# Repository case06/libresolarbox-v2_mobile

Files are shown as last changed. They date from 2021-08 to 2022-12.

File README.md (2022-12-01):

# libresolarbox-v2_mobile

[](
    https://opensourceecology.de)

LibreSolarBox V2 mobile powerbank

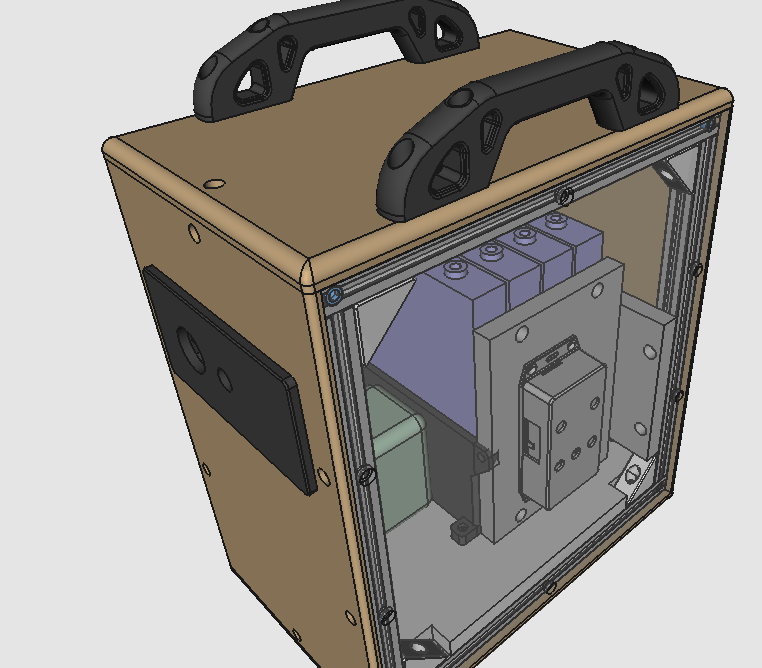
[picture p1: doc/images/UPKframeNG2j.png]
<p></p>

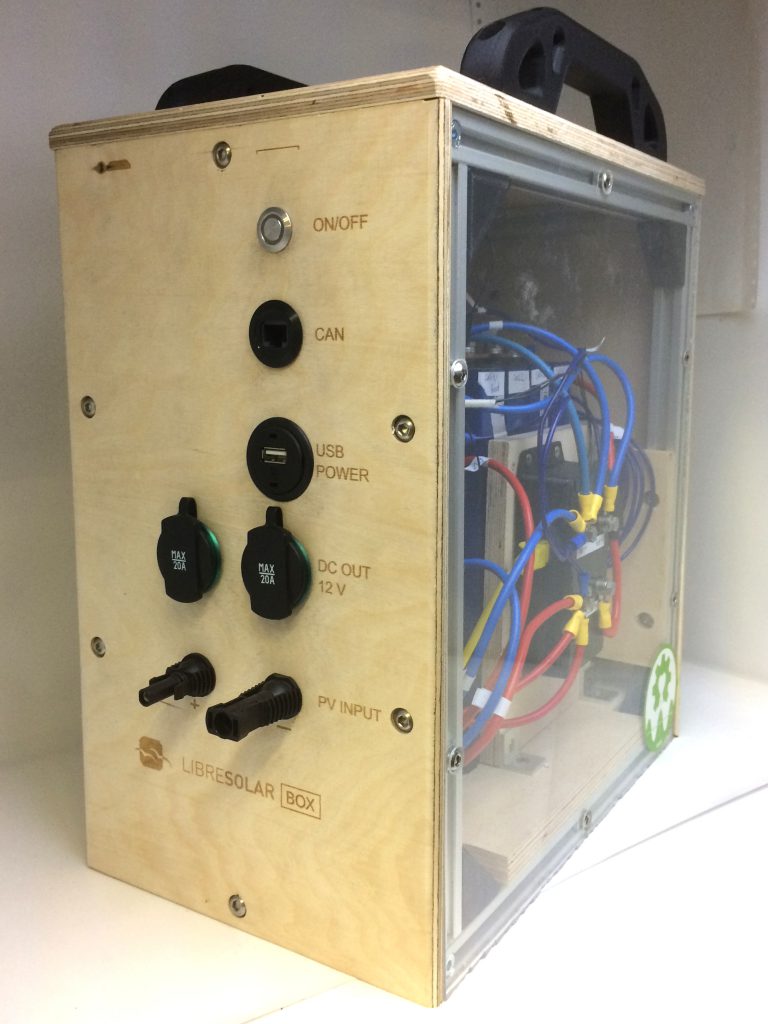
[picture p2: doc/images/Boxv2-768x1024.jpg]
<p></p>

Projektpage(s):

https://wiki.opensourceecology.de/SolarBox#Solarbox_Powerbank

https://github.com/CollectiveOpenSourceHardware/LibreSolarBox

Related projects:

https://libre.solar/

https://learn.libre.solar/

The projekt is based on the UniProKit 3D-part-library UPKlib V2.06, which is available at 

<a href="https://github.com/case06/upklib_v2"> https://github.com/case06/upklib_v2 </a>

The FreeCAD-sourcefiles of the current version can be viewed or modified with FreeCAD version 18 and 19

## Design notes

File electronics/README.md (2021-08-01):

# libresolarbox-v2_mobile electronics
Electronics for LibreSolarBox V2 mobile powerbank

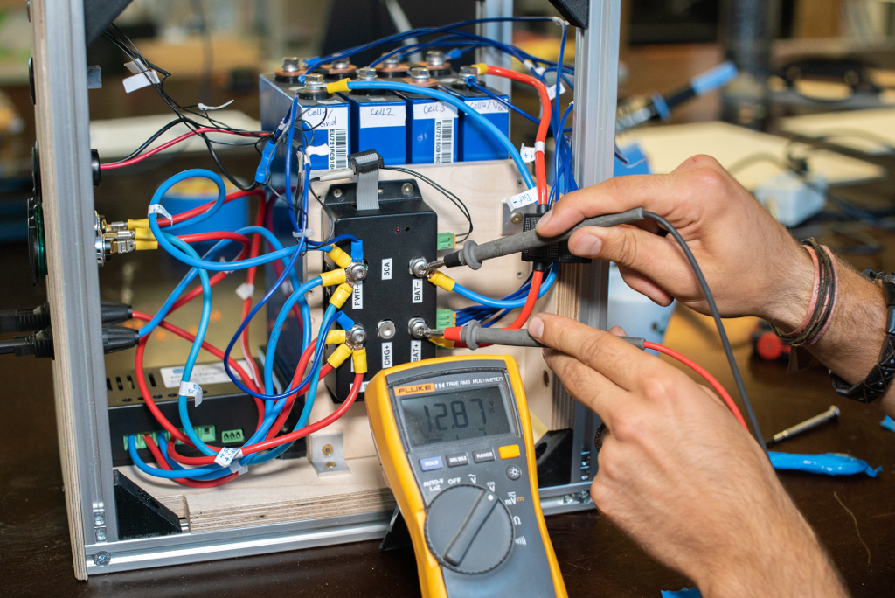
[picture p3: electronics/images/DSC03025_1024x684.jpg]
<p></p>

## Electronics Components:

### PCBs:

The electronic interieur of the Box can be filled with lots of different components from different sources but should in general cover the following basic functions:

- LiFePo4-Cells
- Battery-Managment-System (BMS)
- Solar-Charger
- Interfacing 
- communications gateway

As a reference we relay here to some OpenHardware pcb-versions which were developed by the LibreSolar-project:

#### Solarcharger: MPPT-2420 LC

https://github.com/LibreSolar/mppt-2420-lc

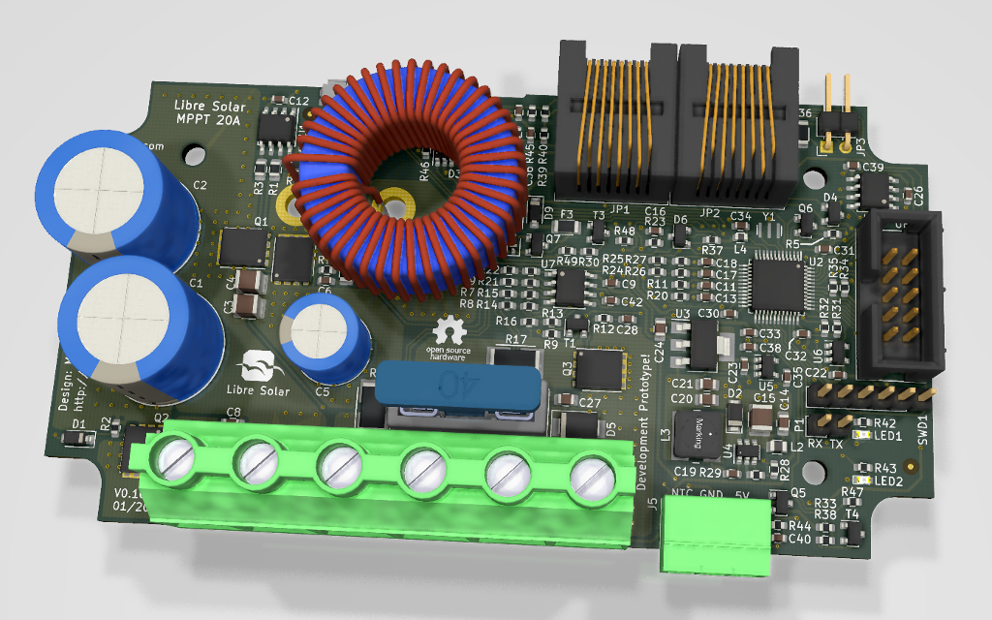
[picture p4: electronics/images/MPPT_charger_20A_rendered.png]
<p></p>
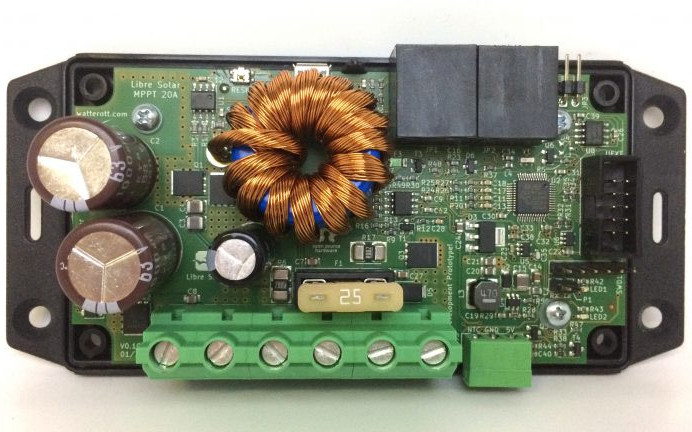
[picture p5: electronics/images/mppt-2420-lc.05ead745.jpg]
<p></p>

#### BatteryManagementSystem: BMS-8s50 IC

https://github.com/LibreSolar/bms-8s50-ic

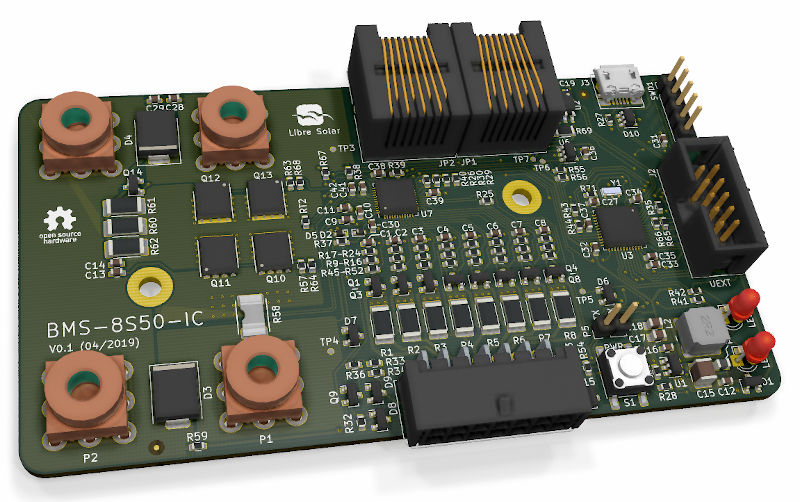
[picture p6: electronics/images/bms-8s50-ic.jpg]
<p></p>
<p></p>

#### Gateway: RPi-Can

https://github.com/LibreSolar/rpi-can

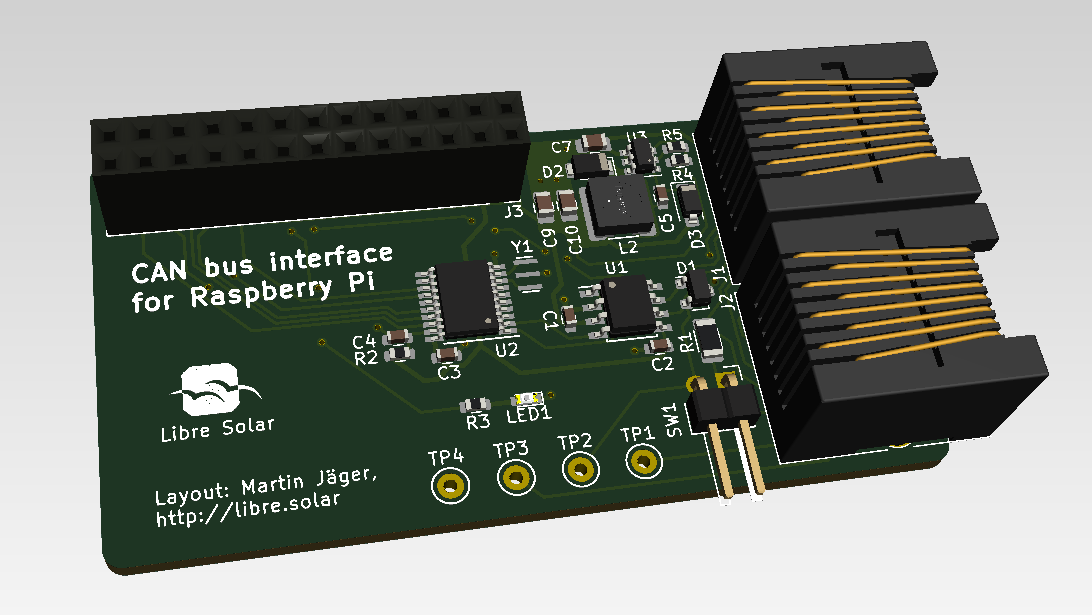
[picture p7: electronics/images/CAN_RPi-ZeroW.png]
<p></p>
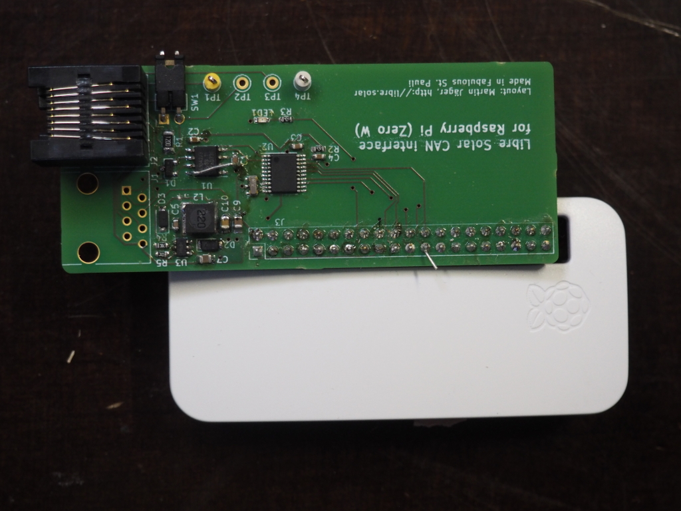
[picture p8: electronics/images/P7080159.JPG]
<p></p>

All other parts are standard-parts from regular sources.

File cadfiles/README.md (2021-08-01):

# libresolarbox_v2_mobile cadfiles
Cadfiles for LibreSolarBox V2 mobile powerbank

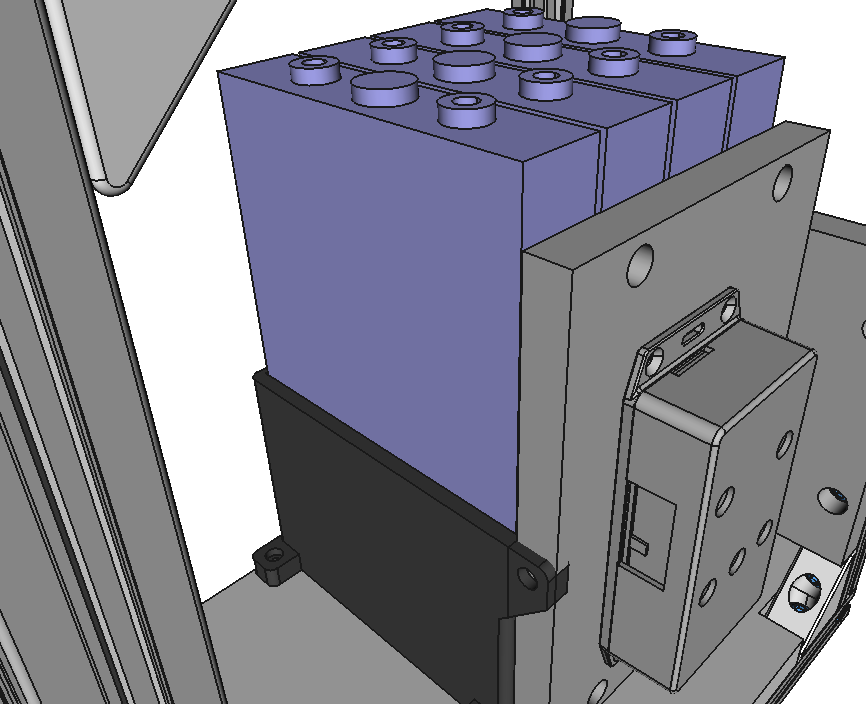
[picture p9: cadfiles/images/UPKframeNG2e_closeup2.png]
LibreSolarBox V2 mobile powerbank
<p></p>

All the parts of the boxframe are available also as singlepart-cadfile within the UPKlib V2 Boxset:

https://github.com/case06/upklib_v2/tree/master/boxset

Projektpage(s):

https://wiki.opensourceecology.de/Upklib#Set_Box

https://wiki.opensourceecology.de/Erg%C3%A4nzungs-Set_Boxset

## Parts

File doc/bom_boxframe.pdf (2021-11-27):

Sheet1

Page 1

BOM BoxSet V.2 mobile UniProKit UPKlib V2.06

Partname | UPK-PartNo. Quantity | Description | Supplier

Frame:
Tslot32 | 17092207 | 4 | Upright framepart | ML
Tslot32con | 17092218 | 4 | Side framepart | ML
Tslot16 | 17092205 | 4 | Cross-link framepart | ML
M6x25cyl | 17092307 | 8 | Screw f. TSlot direct-corner-connection DIN 7984 | SP, ML
M6x12 | 17092304 | 16 | Screw f. Right-Angle-Connector, ISO7380 | SP, ML
M6x16 | 17092305 | 12 | Screw f. connect Mountplates, ISO7380 | SP, ML
M6nutplate | 17092309 | 28 | Nutplate for Right-Angle-Connector | ML
RAconnector | 17092313 | 8 | Right-Angle-Connector, ABS black | 3DP, ML
Front_plate | 17092502 | 2 | Inner Front- and Mountplate | ML
Bottom_plate | 17092501 | 1 | Inner Bottom-Plate | ML
Angle4 | 17092224 | 2 | Connect Mountplates | ML
3.5x16 woodscrew | 18081701 | 16 | Screw f. connect Mountplates DIN 7997 | SP, ML
Handle | 17122301 | 2 | Handle, ABS black | 3DP, ML

Cover:
M6x8 | 17092303 | 24 | Screw f. CoverPlates ISO7380 | SP, ML
M6x25cyl | 17092307 | 8 | Screw f. Handles plus 12mm Plate DIN7984 | SP, ML
M6x12 | 17092304 | 8 | Screw f. TopBottom-Cover ISO7380 | SP, ML
M6nutplate | 17092309 | 40 | Nutplate for CoverPlates | ML
TopBottomNG2b | 18011601 | 2 | Top,Bottom Film Faced Phenolic Plywood 12mm | ML
FrontbackNG2b | 18011602 | 1 | Front Cover Film Faced Phenolic Plywood 6.5mm | ML
FrontbackNG2c_ifmount | 18011603 | 1 | Back Cover Film Faced Phenolic Plywood 6.5mm | ML
SideCoverNG2_transp | 18011604 | 1 | Side Cover Acryl-glas 6mm | ML
SideCoverNG2 | 18081702 | 1 | Side Cover Film Faced Phenolic Plywood 6.5mm | ML
IfmountNG1c | 18050303 | 1 | Interface mountplate, ABS black | 3DP, ML

Sheet1

Page 2

Std.-Part | SP Standard-Part, widely available from several sources
3d-Printable | 3DP 3d-printable part, see project sources

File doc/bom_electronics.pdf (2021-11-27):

Sheet1

Page 1

BOM Electronics LibreSolarBox V.2 mobile

Partname | UPK-PartNo. Quantity | Description | Supplier

housing

All UPKlib boxset parts | | External Project | EPS1
batterymount 1c | 1 | Holder for LiFePo4-cells | 3DP
bms-case1c | 1 | Housing for BMS pcb | 3DP
mppt-2420lc-housing | 1 | Hammond Mfg 1591XXCFL housing | SP

Solarcharger:

LibreSolar_MPPT-Charger_20A | 1 | EPS2

BMS:
LibreSolar_BMS-5s | 1 | EPS3

Gateway:
RPi-Can | 1 | External Project, optional | EPS4

Buck-Converter:

Buck-Converter-12-5 | 1 | Buck-Converter from 12V to 5V, optional | SP

Interface:

Display | 1 | | SP
DC_Out_Plug1 | 1 | DC output plugs (12V car plug, 2x) | SP
USB_adapter | 1 | USB 5V outlet plug w/ integr. 12V→5V stepdown | SP
PV_in_MC4 | 2 | SP

MPPT-2420 LC, External Project

BMS-8s50 IC, External Project

i2c character display or - e-paper display+cable, Optional

Pair of MC4 Solar input plugs, eg. Weidmüller PV Stick

Sheet1

Page 2

SW_Push_LED | 1 | ON/OFF switch, pushbutton, integrated LED | SP
CAN output plug | 2 | RJ45 jack, optional | SP

Internal Connections and Hardware:

Power wire | 2 | Power wire (6mm^2, red+blue, each 1m) | SP
Balancer cable | 1 | Balancing wire for Cells (2mm^2, 2m) | SP
Wire - thick - red & blue | 10 | | SP
Wire - thin - blue | 6 | | SP
Wire - very thin - black | 3 | | SP
Cat5 cable | 3 | | SP
F1 – Fuse | 1 | 20A | SP
wire connectors | 1 | | SP
Battery Cell | 4 | CALB 72 Ah CAM, LiFePo4 | SP
Battery Cell connector plates | 3 | for CAM72, copper | SP
Battery Cell connector screw | 8 | | SP
RasPi - CAN to wifi connection | 1 | | SP
Screw - MPPT/BMS connection | 10 | 5x2 | SP
Screw - MPPT/BMS installation | 8 | 4x2 | SP
Ferrules | 1 | Set with 6mm^2 and 2mm^2 | SP
Cable lugs | 1 | | SP

to all main connection from battery to MPPT & BMS 0.25m (5 Red color & 5 Blue colour)

to connect BMS to battery to check Battery status 0.4mx6 (blue colour)

to connect power button to MPPT,
0.25mx2, 0.4mx1

CAN communication wire (ethernet cable, 0,25m), Optional

M8x10, DIN 912

Set with flat- and ring-lugs of different hole-sizes (8, 6, 5mm)

Sheet1

Page 3

Supplier | Id | URL
Std.-Part | SP | Standard-Part, widely available from several sources
Makers-Lab | ML | http:makers-lab.de
3d-Printable | 3DP | 3d-printable part, see project sources
external project | EPS | Sources from an external project
external project | EPS1 | https://github.com/case06/upklib_v2/tree/master/boxset
external project | EPS2 | https://github.com/LibreSolar/mppt-2420-lc
external project | EPS3 | https://github.com/LibreSolar/bms-8s50-ic
external project | EPS4 | https://github.com/LibreSolar/rpi-can

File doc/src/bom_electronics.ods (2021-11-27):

BOM Electronics LibreSolarBox V.2 mobile
Partname |  | UPK-PartNo. | Quantity | Description | Supplier
housing
All UPKlib boxset parts |  |  |  | External Project | EPS1
batterymount 1c |  |  | 1 | Holder for LiFePo4-cells | 3DP
bms-case1c |  |  | 1 | Housing for BMS pcb | 3DP
mppt-2420lc-housing |  |  | 1 | Hammond Mfg 1591XXCFL housing | SP
Solarcharger:
LibreSolar_MPPT-Charger_20A |  |  | 1 | MPPT-2420 LC, External Project | EPS2
BMS:
LibreSolar_BMS-5s |  |  | 1 | BMS-8s50 IC, External Project | EPS3
Gateway:
RPi-Can |  |  | 1 | External Project, optional | EPS4
Buck-Converter:
Buck-Converter-12-5 |  |  | 1 | Buck-Converter from 12V to 5V, optional | SP
Interface:
Display |  |  | 1 | i2c character display or - e-paper display+cable, Optional | SP
DC_Out_Plug1 |  |  | 1 | DC output plugs (12V car plug, 2x) | SP
USB_adapter |  |  | 1 | USB 5V outlet plug w/ integr. 12V→5V stepdown | SP
PV_in_MC4 |  |  | 2 | Pair of MC4 Solar input plugs, eg. Weidmüller PV Stick | SP
SW_Push_LED |  |  | 1 | ON/OFF switch, pushbutton, integrated LED | SP
CAN output plug |  |  | 2 | RJ45 jack, optional | SP
Internal Connections and Hardware:
Power wire |  |  | 2 | Power wire (6mm^2, red+blue, each 1m) | SP
Balancer cable |  |  | 1 | Balancing wire for Cells (2mm^2, 2m) | SP
Wire - thick - red & blue |  |  | 10 | to all main connection from battery to MPPT & BMS 0.25m (5 Red color & 5 Blue colour) | SP
Wire - thin - blue |  |  | 6 | to connect BMS to battery to check Battery status 0.4mx6 (blue colour) | SP
Wire - very thin - black |  |  | 3 | to connect power button to MPPT, 0.25mx2, 0.4mx1 | SP
Cat5 cable |  |  | 3 | CAN communication wire (ethernet cable, 0,25m), Optional | SP
F1 – Fuse |  |  | 1 | 20A | SP
wire connectors |  |  | 1 |  | SP
Battery Cell |  |  | 4 | CALB 72 Ah CAM, LiFePo4 | SP
Battery Cell connector plates |  |  | 3 | for CAM72, copper | SP
Battery Cell connector screw |  |  | 8 | M8x10, DIN 912 | SP
RasPi - CAN to wifi connection |  |  | 1 |  | SP
Screw - MPPT/BMS connection |  |  | 10 | 5x2 | SP
Screw - MPPT/BMS installation |  |  | 8 | 4x2 | SP
Ferrules |  |  | 1 | Set with 6mm^2 and 2mm^2 | SP
Cable lugs |  |  | 1 | Set with flat- and ring-lugs of different hole-sizes (8, 6, 5mm) | SP
Supplier | Id | URL
Std.-Part | SP | Standard-Part, widely available from several sources
Makers-Lab | ML | http:makers-lab.de
3d-Printable | 3DP | 3d-printable part, see project sources
external project | EPS | Sources from an external project
external project | EPS1 | https://github.com/case06/upklib_v2/tree/master/boxset
external project | EPS2 | https://github.com/LibreSolar/mppt-2420-lc
external project | EPS3 | https://github.com/LibreSolar/bms-8s50-ic
external project | EPS4 | https://github.com/LibreSolar/rpi-can

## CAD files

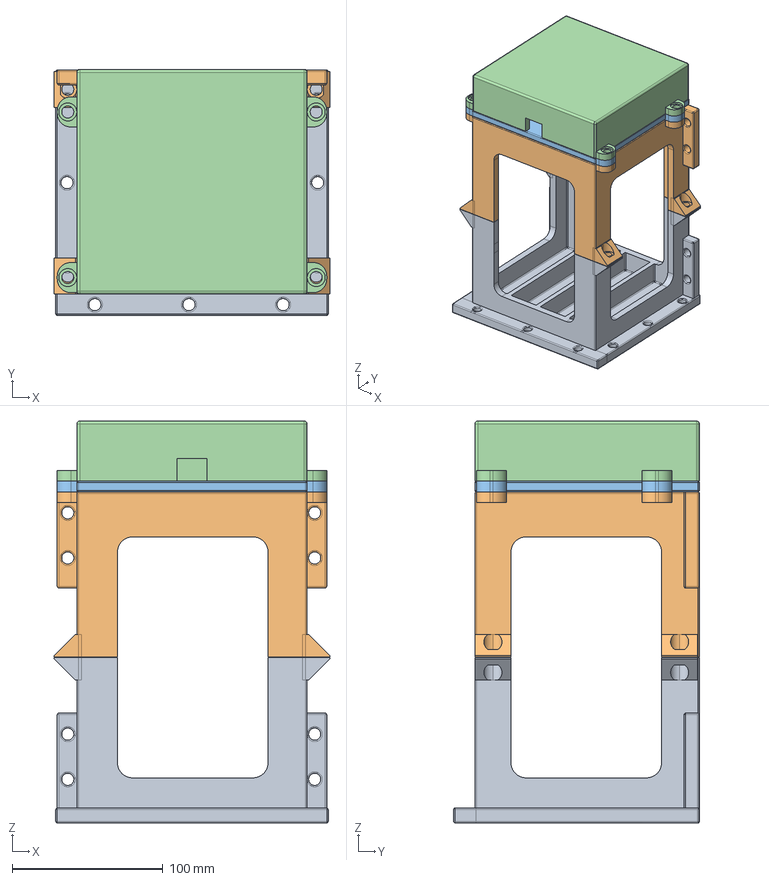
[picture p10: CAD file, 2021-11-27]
cadfiles/batterymount_full-closure.FCStd
183.0 x 163.2 x 267.0 mm
Lower_part_1
Upper_part_2
Top_sheet_3
Cover_part_4

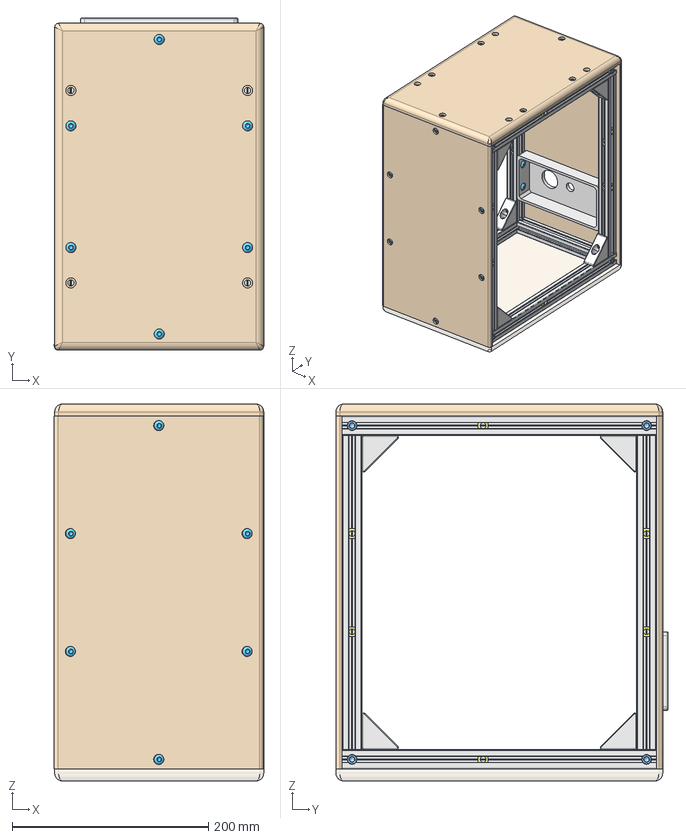
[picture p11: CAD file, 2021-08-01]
doc/src/src_boxassemblyguide1d/cover/cover8.fcstd
213.5 x 338.5 x 384.0 mm
tslot32con
tslot16
tslot16_001
tslot32con_001
M6x25-Screw
M6x25-Screw004
M6x25-Screw005
M6x25-Screw006
tslot32con001
tslot041
tslot16_002
tslot32con_002
M6x25-Screw012
M6x25-Screw015
M6x25-Screw017
M6x25-Screw016
m6nutplate020uf
m6nutplate021lf
m6nutplate022lf
m6nutplate023lf
m6nutplate024lf
m6nutplate025lf
m6nutplate026lf
m6nutplate027lf
m6nutplate028uf
m6nutplate029uf
m6nutplate030lf
m6nutplate031lf
m6nutplate032uf
m6nutplate033lf
upright4
m6nutplate025uf001
m6nutplate022uf001
m6nutplate031lf001
M6x12-Screw022
upright005
m6nutplate031lf002
M6x12-Screw025
upright006
m6nutplate031lf003
M6x12-Screw028
upright007
m6nutplate031lf004
M6x12-Screw031
m6nutplatesidecover
m6nutplatesidecover001
m6nutplatesidecover002
m6nutplatesidecover003
m6nutplatesidecover004
m6nutplatesidecover005
m6nutplatesidecover006
m6nutplatesidecover007
m6nutplatefrontcover
m6nutplatefrontcover001
m6nutplatefrontcover002
m6nutplatefrontcover003
m6nutplatefrontcover004
m6nutplatefrontcover005
m6nutplatefrontcover006
m6nutplatefrontcover007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

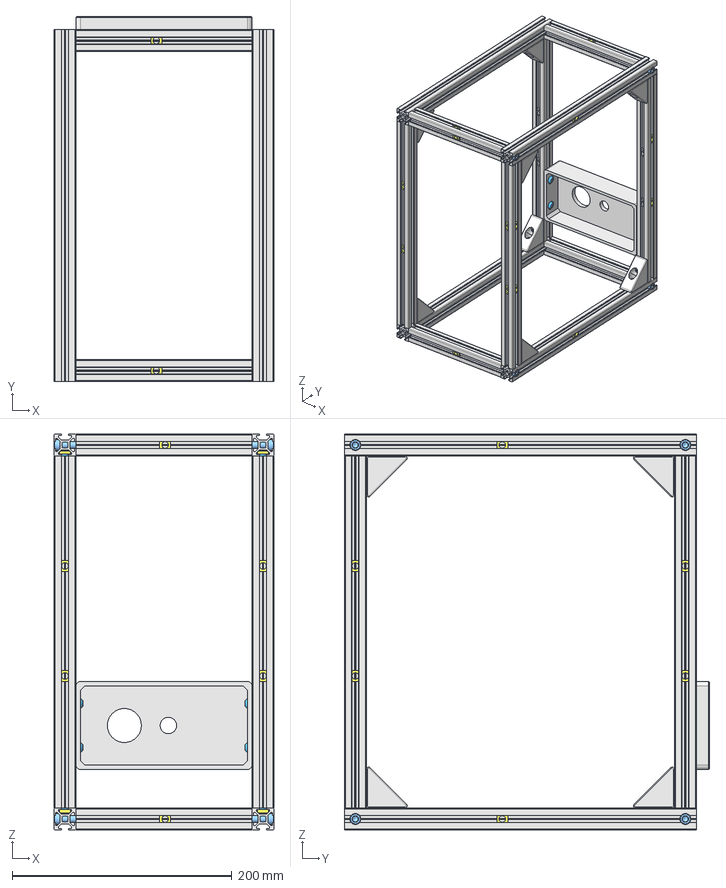
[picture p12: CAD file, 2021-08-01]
doc/src/src_boxassemblyguide1d/ifmountframe/ifmountframe1.fcstd
200.0 x 332.0 x 360.0 mm
tslot32con
tslot16
tslot16_001
tslot32con_001
M6x25-Screw
M6x25-Screw004
M6x25-Screw005
M6x25-Screw006
tslot32con001
tslot041
tslot16_002
tslot32con_002
M6x25-Screw012
M6x25-Screw015
M6x25-Screw017
M6x25-Screw016
m6nutplate020uf
m6nutplate021lf
m6nutplate022lf
m6nutplate023lf
m6nutplate024lf
m6nutplate025lf
m6nutplate026lf
m6nutplate027lf
m6nutplate028uf
m6nutplate029uf
m6nutplate030lf
m6nutplate031lf
m6nutplate032uf
m6nutplate033lf
upright4
m6nutplate025uf001
m6nutplate022uf001
m6nutplate031lf001
M6x12-Screw022
upright005
m6nutplate031lf002
M6x12-Screw025
upright006
m6nutplate031lf003
M6x12-Screw028
upright007
m6nutplate031lf004
M6x12-Screw031
m6nutplatesidecover
m6nutplatesidecover001
m6nutplatesidecover002
m6nutplatesidecover003
m6nutplatesidecover004
m6nutplatesidecover005
m6nutplatesidecover006
m6nutplatesidecover007
m6nutplatefrontcover
m6nutplatefrontcover001
m6nutplatefrontcover002
m6nutplatefrontcover003
m6nutplatefrontcover004
m6nutplatefrontcover005
m6nutplatefrontcover006
m6nutplatefrontcover007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

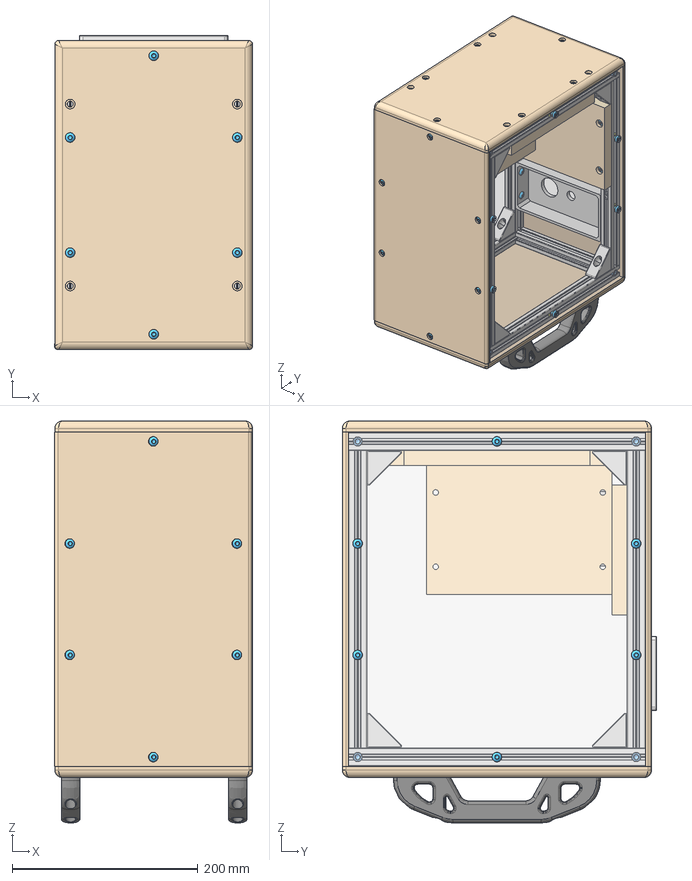
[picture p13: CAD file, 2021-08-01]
doc/src/src_boxassemblyguide1d/innerplates/innerplate6.fcstd
213.5 x 338.5 x 433.0 mm
tslot32con
tslot16
tslot16_001
tslot32con_001
M6x25-Screw
M6x25-Screw004
M6x25-Screw005
M6x25-Screw006
tslot32con001
tslot041
tslot16_002
tslot32con_002
M6x25-Screw012
M6x25-Screw015
M6x25-Screw017
M6x25-Screw016
m6nutplate020uf
m6nutplate021lf
m6nutplate022lf
m6nutplate023lf
m6nutplate024lf
m6nutplate025lf
m6nutplate026lf
m6nutplate027lf
m6nutplate028uf
m6nutplate029uf
m6nutplate030lf
m6nutplate031lf
m6nutplate032uf
m6nutplate033lf
m6nutplate023
upright4
m6nutplate025uf001
m6nutplate022uf001
m6nutplate031lf001
M6x12-Screw022
upright005
m6nutplate031lf002
M6x12-Screw025
upright006
m6nutplate031lf003
M6x12-Screw028
upright007
m6nutplate031lf004
M6x12-Screw031
m6nutplatesidecover
m6nutplatesidecover001
m6nutplatesidecover002
m6nutplatesidecover003
m6nutplatesidecover004
m6nutplatesidecover005
m6nutplatesidecover006
m6nutplatesidecover007
m6nutplatefrontcover
m6nutplatefrontcover001
m6nutplatefrontcover002
m6nutplatefrontcover003
m6nutplatefrontcover004
m6nutplatefrontcover005
m6nutplatefrontcover006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

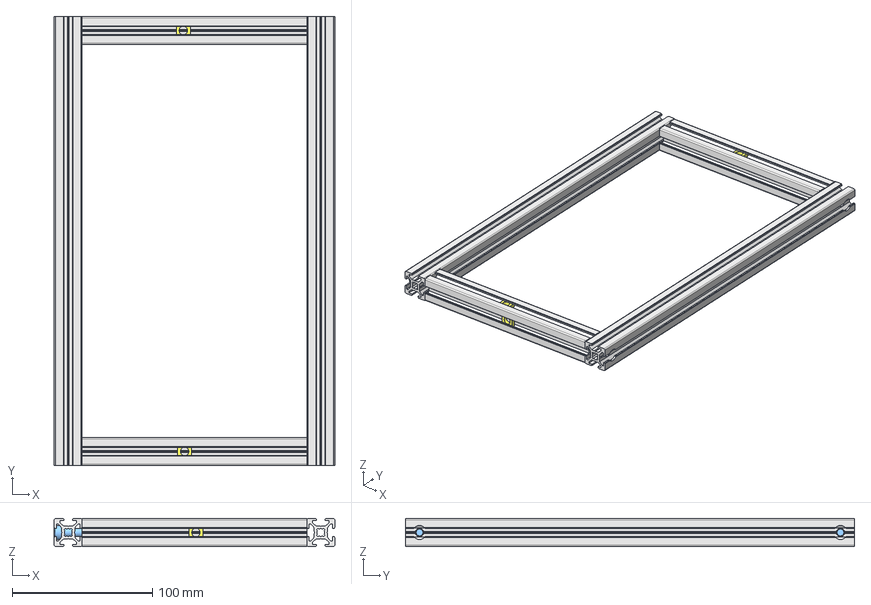
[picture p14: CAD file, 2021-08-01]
doc/src/src_boxassemblyguide1d/lower_frame/lowerframe1.fcstd
200.0 x 320.0 x 20.0 mm
tslot32con001
tslot041
tslot16_002
tslot32con_002
M6x25-Screw007
M6x25-Screw008
m6nutplate020
m6nutplate021
m6nutplate022
m6nutplate023
m6nutplate024
m6nutplate025
m6nutplate026
m6nutplate027

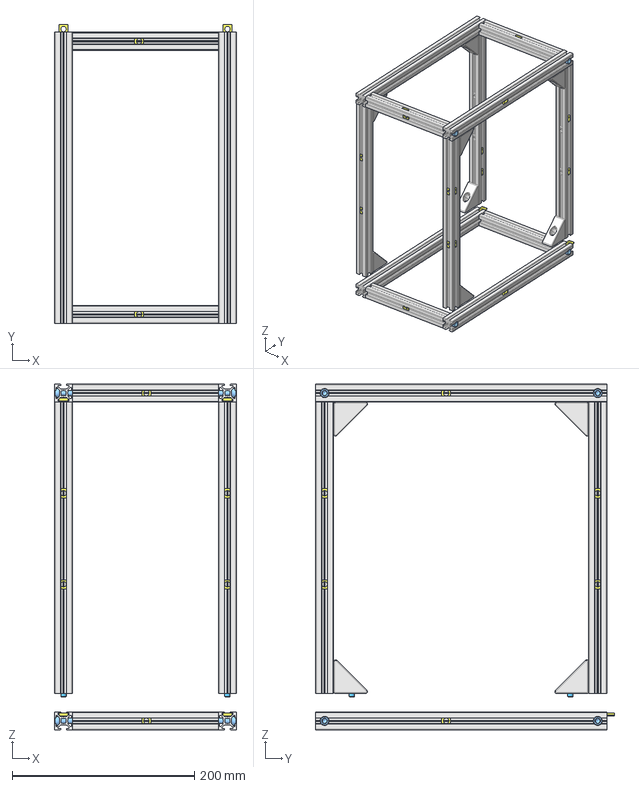
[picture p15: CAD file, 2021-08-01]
doc/src/src_boxassemblyguide1d/rawframe/rawframe8b.fcstd
200.0 x 328.4 x 380.0 mm
tslot32con
tslot16
tslot16_001
tslot32con_001
M6x25-Screw
M6x25-Screw004
M6x25-Screw005
M6x25-Screw006
tslot32con001
tslot041
tslot16_002
tslot32con_002
M6x25-Screw012
M6x25-Screw015
M6x25-Screw017
M6x25-Screw016
m6nutplate020uf
m6nutplate021lf
m6nutplate022lf
m6nutplate023lf
m6nutplate024lf
m6nutplate025lf
m6nutplate026lf
m6nutplate027lf
m6nutplate028uf
m6nutplate029uf
m6nutplate030lf
m6nutplate031lf
m6nutplate032uf
m6nutplate033lf
upright4
m6nutplate025uf001
m6nutplate022uf001
m6nutplate031lf001
M6x12-Screw022
upright005
m6nutplate031lf002
M6x12-Screw025
upright006
m6nutplate031lf003
M6x12-Screw028
upright007
m6nutplate031lf004
M6x12-Screw031
m6nutplatesidecover
m6nutplatesidecover001
m6nutplatesidecover002
m6nutplatesidecover003
m6nutplatesidecover004
m6nutplatesidecover005
m6nutplatesidecover006
m6nutplatesidecover007
m6nutplatefrontcover
m6nutplatefrontcover001
m6nutplatefrontcover002
m6nutplatefrontcover003
m6nutplatefrontcover004
m6nutplatefrontcover005
m6nutplatefrontcover006
m6nutplatefrontcover007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

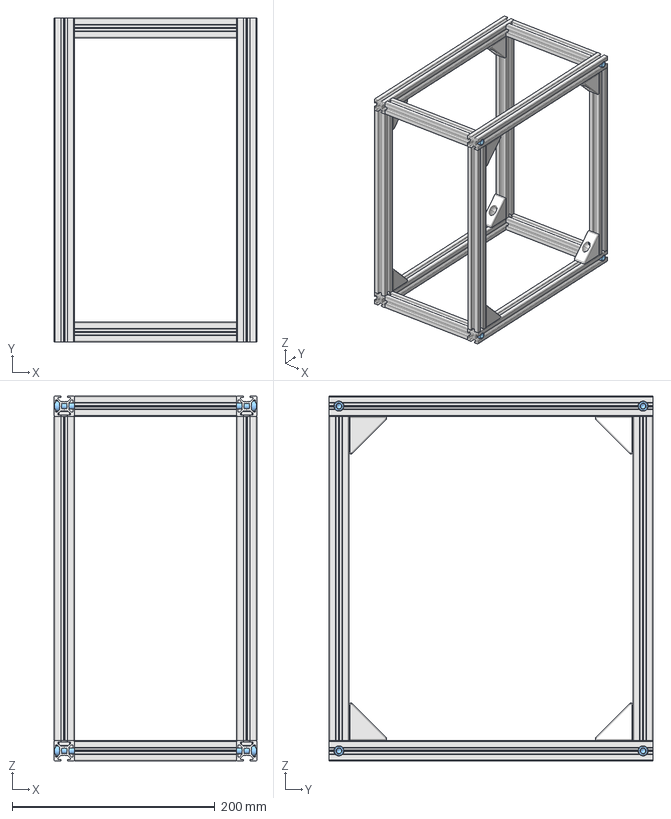
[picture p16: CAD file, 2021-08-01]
doc/src/src_boxassemblyguide1d/rawframeNG2b.fcstd
200.0 x 320.0 x 360.0 mm
tslot32con
tslot16
tslot16_001
tslot32con_001
M6x25-Screw
M6x25-Screw004
M6x25-Screw005
M6x25-Screw006
tslot32con001
tslot041
tslot16_002
tslot32con_002
M6x25-Screw007
M6x25-Screw008
M6x25-Screw009
M6x25-Screw010
m6nutplate002
M6x12-Screw002
M6x12-Screw003
m6nutplate003
m6nutplate
M6x12-Screw
M6x12-Screw001
m6nutplate001
m6nutplate004
M6x12-Screw004
M6x12-Screw005
m6nutplate005
m6nutplate006
M6x12-Screw006
M6x12-Screw007
m6nutplate007
tslot32
tslot32_001
tslot32_002
tslot32_003

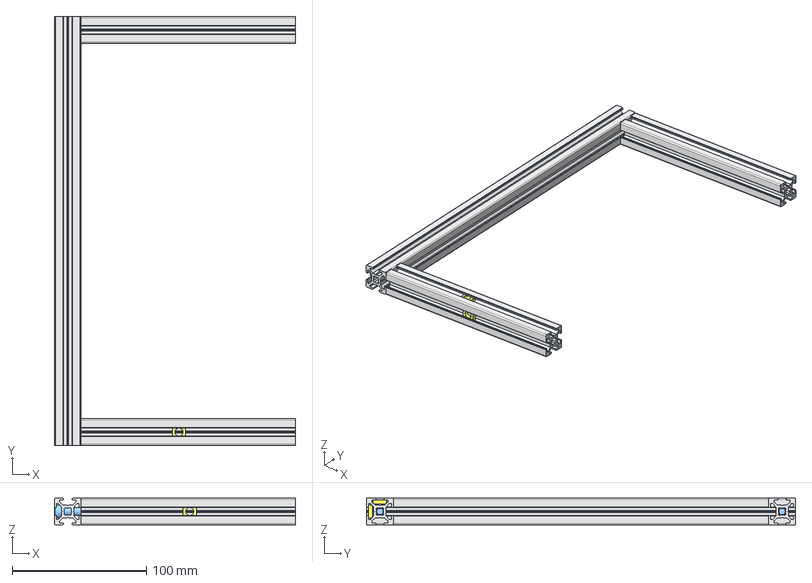
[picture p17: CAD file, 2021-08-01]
doc/src/src_boxassemblyguide1d/upper_frame/upperframe1.fcstd
180.0 x 320.0 x 20.0 mm
tslot32con001
tslot041
tslot16_002
M6x25-Screw007
M6x25-Screw008
m6nutplate020
m6nutplate021

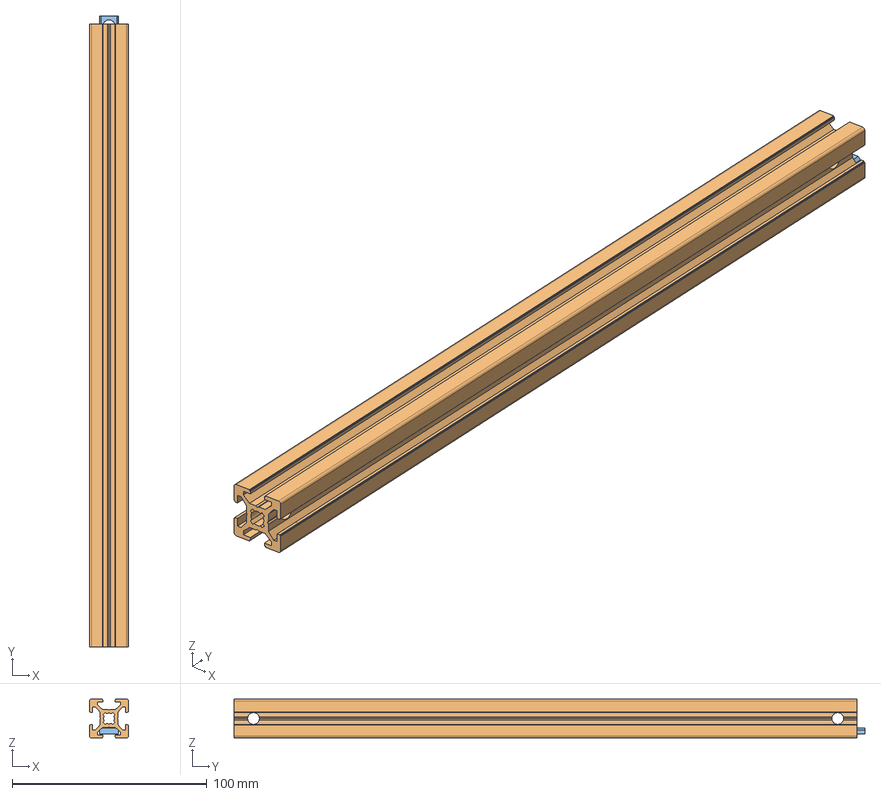
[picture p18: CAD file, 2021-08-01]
doc/src/src_boxassemblyguide1d/upright/upright2.fcstd
20.0 x 324.0 x 20.0 mm
m6nutplate

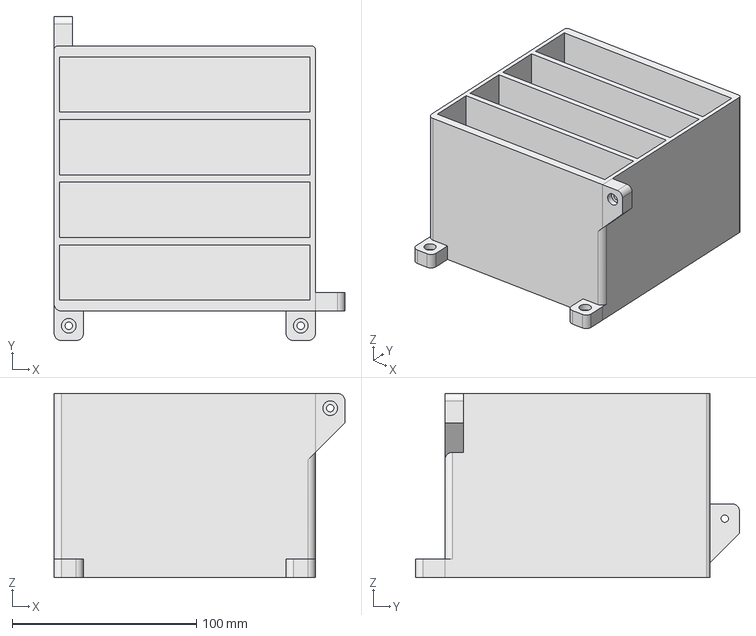
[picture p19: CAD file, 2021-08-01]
cadfiles/batterymount1c.fcstd
158.0 x 176.0 x 100.0 mm

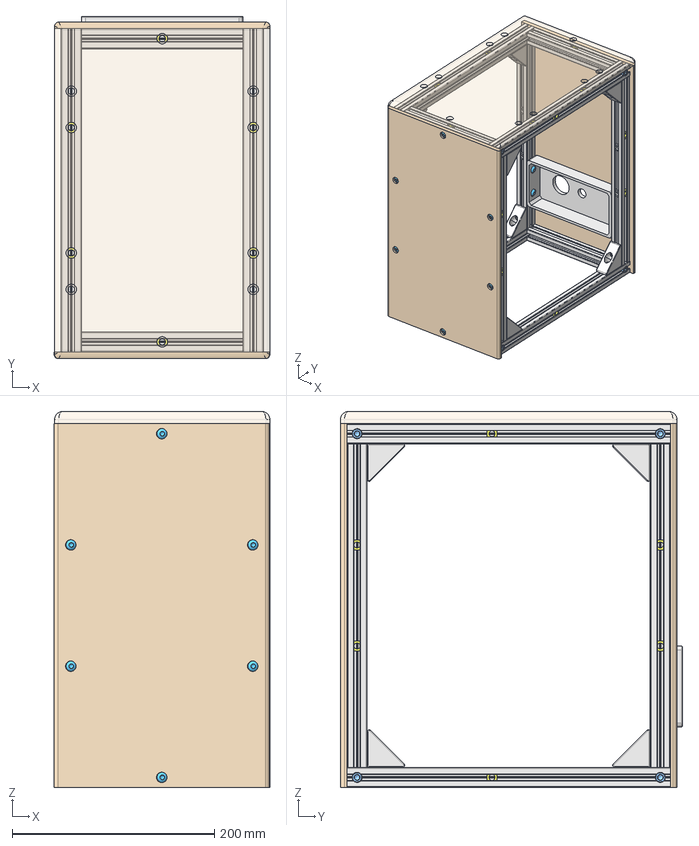
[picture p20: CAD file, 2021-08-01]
doc/src/src_boxassemblyguide1d/cover/cover6.fcstd
213.5 x 338.5 x 372.0 mm
tslot32con
tslot16
tslot16_001
tslot32con_001
M6x25-Screw
M6x25-Screw004
M6x25-Screw005
M6x25-Screw006
tslot32con001
tslot041
tslot16_002
tslot32con_002
M6x25-Screw012
M6x25-Screw015
M6x25-Screw017
M6x25-Screw016
m6nutplate020uf
m6nutplate021lf
m6nutplate022lf
m6nutplate023lf
m6nutplate024lf
m6nutplate025lf
m6nutplate026lf
m6nutplate027lf
m6nutplate028uf
m6nutplate029uf
m6nutplate030lf
m6nutplate031lf
m6nutplate032uf
m6nutplate033lf
upright4
m6nutplate025uf001
m6nutplate022uf001
m6nutplate031lf001
M6x12-Screw022
upright005
m6nutplate031lf002
M6x12-Screw025
upright006
m6nutplate031lf003
M6x12-Screw028
upright007
m6nutplate031lf004
M6x12-Screw031
m6nutplatesidecover
m6nutplatesidecover001
m6nutplatesidecover002
m6nutplatesidecover003
m6nutplatesidecover004
m6nutplatesidecover005
m6nutplatesidecover006
m6nutplatesidecover007
m6nutplatefrontcover
m6nutplatefrontcover001
m6nutplatefrontcover002
m6nutplatefrontcover003
m6nutplatefrontcover004
m6nutplatefrontcover005
m6nutplatefrontcover006
m6nutplatefrontcover007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

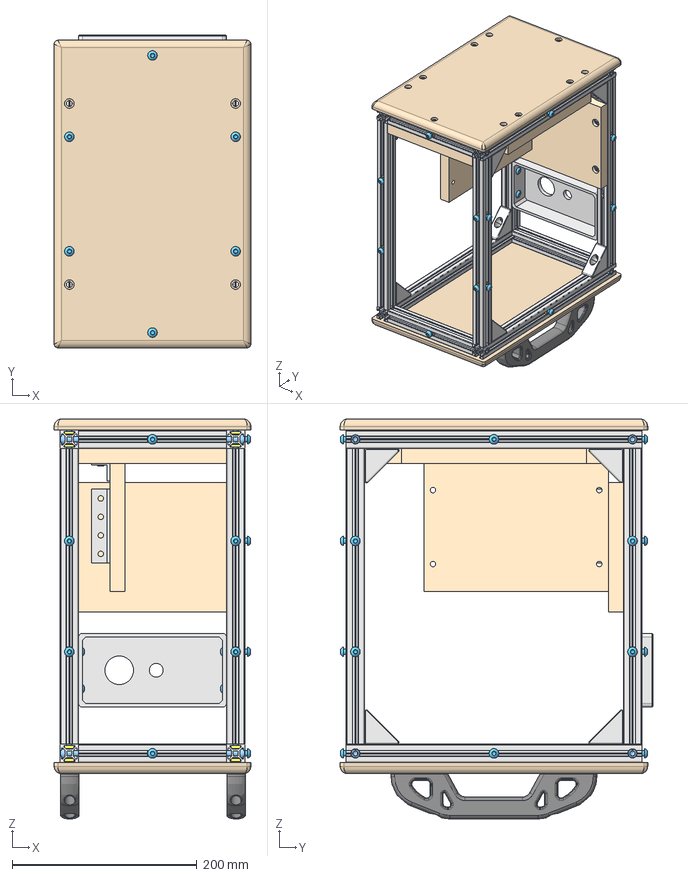
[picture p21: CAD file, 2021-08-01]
doc/src/src_boxassemblyguide1d/innerplates/innerplate5.fcstd
213.0 x 338.5 x 433.0 mm
tslot32con
tslot16
tslot16_001
tslot32con_001
M6x25-Screw
M6x25-Screw004
M6x25-Screw005
M6x25-Screw006
tslot32con001
tslot041
tslot16_002
tslot32con_002
M6x25-Screw012
M6x25-Screw015
M6x25-Screw017
M6x25-Screw016
m6nutplate020uf
m6nutplate021lf
m6nutplate022lf
m6nutplate023lf
m6nutplate024lf
m6nutplate025lf
m6nutplate026lf
m6nutplate027lf
m6nutplate028uf
m6nutplate029uf
m6nutplate030lf
m6nutplate031lf
m6nutplate032uf
m6nutplate033lf
m6nutplate023
upright4
m6nutplate025uf001
m6nutplate022uf001
m6nutplate031lf001
M6x12-Screw022
upright005
m6nutplate031lf002
M6x12-Screw025
upright006
m6nutplate031lf003
M6x12-Screw028
upright007
m6nutplate031lf004
M6x12-Screw031
m6nutplatesidecover
m6nutplatesidecover001
m6nutplatesidecover002
m6nutplatesidecover003
m6nutplatesidecover004
m6nutplatesidecover005
m6nutplatesidecover006
m6nutplatesidecover007
m6nutplatefrontcover
m6nutplatefrontcover001
m6nutplatefrontcover002
m6nutplatefrontcover003
m6nutplatefrontcover004
m6nutplatefrontcover005
m6nutplatefrontcover006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

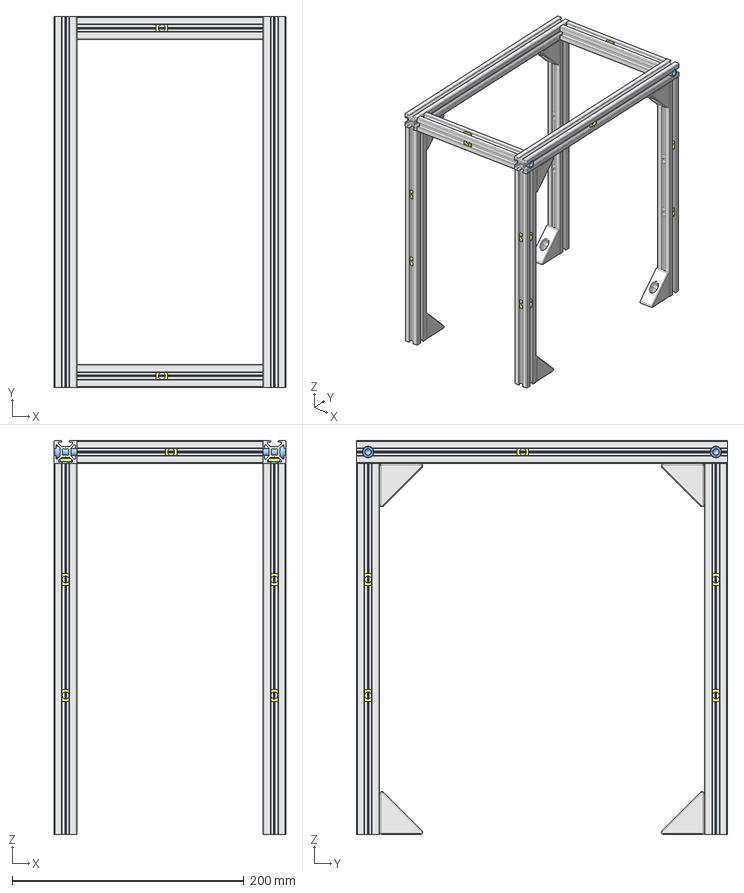
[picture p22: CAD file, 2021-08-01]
doc/src/src_boxassemblyguide1d/rawframe/rawframe6.fcstd
200.0 x 320.0 x 340.0 mm
tslot32con001
tslot041
tslot16_002
tslot32con_002
M6x25-Screw012
M6x25-Screw015
M6x25-Screw017
M6x25-Screw016
m6nutplate021lf
m6nutplate022lf
m6nutplate023lf
m6nutplate024lf
m6nutplate025lf
m6nutplate026lf
m6nutplate027lf
m6nutplate030lf
m6nutplate031lf
m6nutplate033lf
upright4
m6nutplate031lf001
M6x12-Screw022
upright005
m6nutplate031lf002
M6x12-Screw025
upright006
m6nutplate031lf003
M6x12-Screw028
upright007
m6nutplate031lf004
M6x12-Screw031
m6nutplatesidecover
m6nutplatesidecover001
m6nutplatesidecover002
m6nutplatesidecover003
m6nutplatesidecover004
m6nutplatesidecover005
m6nutplatesidecover006
m6nutplatesidecover007
m6nutplatefrontcover
m6nutplatefrontcover001
m6nutplatefrontcover002
m6nutplatefrontcover003
m6nutplatefrontcover004
m6nutplatefrontcover005
m6nutplatefrontcover006
m6nutplatefrontcover007

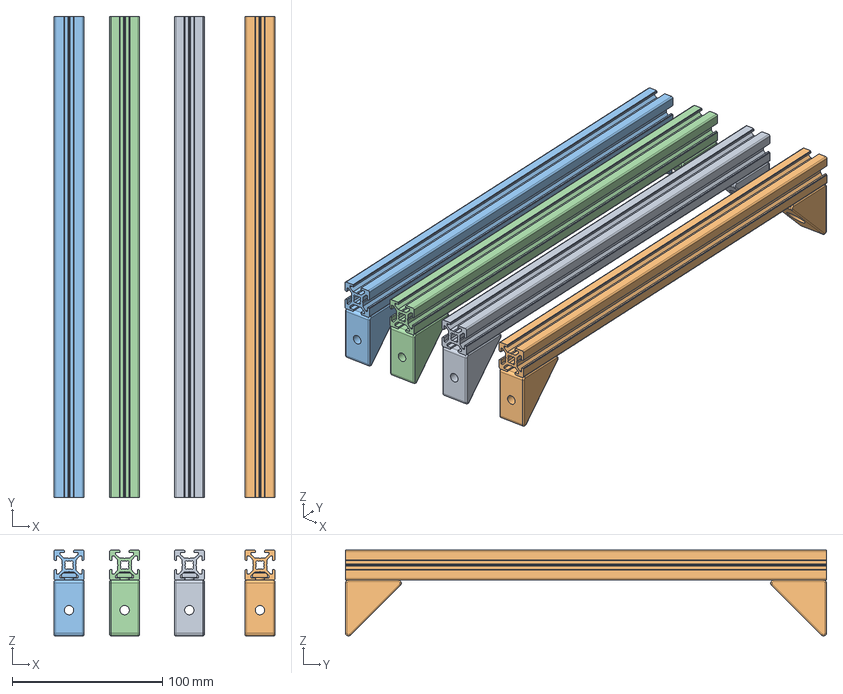
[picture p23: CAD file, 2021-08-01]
doc/src/src_boxassemblyguide1d/upright/upright4b.fcstd
147.0 x 320.0 x 57.2 mm

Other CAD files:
doc/src/src_boxassemblyguide1d/upper_frame/upperframe12.fcstd
cadfiles/SolarBox_allparts.FCStd
doc/src/src_boxassemblyguide1d/cover/cover1.fcstd
doc/src/src_boxassemblyguide1d/innerplates/innerplate1.fcstd
cadfiles/cam72_calb3.fcstd
doc/src/src_boxassemblyguide1d/cover/cover10.fcstd
doc/src/src_boxassemblyguide1d/cover/cover11.fcstd
doc/src/src_boxassemblyguide1d/cover/cover12.fcstd
doc/src/src_boxassemblyguide1d/cover/cover2.fcstd
doc/src/src_boxassemblyguide1d/cover/cover3.fcstd
doc/src/src_boxassemblyguide1d/cover/cover4.fcstd
doc/src/src_boxassemblyguide1d/cover/cover5.fcstd
doc/src/src_boxassemblyguide1d/cover/cover5b.fcstd
doc/src/src_boxassemblyguide1d/cover/cover7.fcstd
doc/src/src_boxassemblyguide1d/cover/cover9.fcstd
doc/src/src_boxassemblyguide1d/innerplates/innerplate2.fcstd
doc/src/src_boxassemblyguide1d/innerplates/innerplate3.fcstd
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

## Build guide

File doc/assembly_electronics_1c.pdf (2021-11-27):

## LibreSolarBox assembly guide

DISCLAIMER

Please notice our following disclaimer. Due to the fact we are not providing a product in the legal sense, we are also not providing any

we are also not providing any warranty in any aspect.

The construction manual described here has been developed and tested by the team of cos(h) with care and to the best of our knowledge.

The team assumes no liability for the accuracy, completeness or quality of the information provided for the construction of the hardware described.

Liability claims against the team for material, physical or immaterial damages caused by the use or non-use of the information provided or by the use

of incorrect and/or incomplete information are excluded.

All information and instructions are non-binding. The team expressly reserves the right to change, supplement or delete parts of the pages or the entire

offer without prior notice or to cease publication temporarily or permanently. By using the construction manual, the user accepts this disclaimer.

This document contains excerpts from the gos(h)-groups libresolarbox-projectpage at https://github.com/CollectiveOpenSourceHardware/LibreSolarBox .

Some of them were recorded during the Assembly Workshop at the Fablab St.Pauli, 08. July 2018

## Environment and Tools

Preparation Steps

- Software tools
- FreeCAD,
- Prepare tools and place

-> foto of each part

- table
- crimping tool
- screwdriver
- side cutter
- allen wrench
- Prepare material and components
- Frame and Housing (in this case UniProKit)
- screws, nuts

- T-slot alu profile
- 3D printed corner elements / connectors
- bottom plate
- housing plates
- Battery pack
- 3D printed battery case (bottom and cap -> download link to file)
- battery cells
- cell connectors
- electrical components
- Libre Solar components -> MPPT, *BMS*, (optional: CAN2Wifi)
- (optional: RaspberryPi0)
- wires - power wires (6 sq mm), balancing wires (2 sq mm)
- ferrules, cable lugs
- (optional: communication wire - ethernet cable)
- plugs
- *dc-output plugs (car plug, 2x)*
- solar input plugs (Weidmüller PV Stick allows assembly w/o crimping and is compatible to MC4. Clips should be removed that the plug

can be unmounted without tools)

- *usb plugs*
- *ON/OFF switch, pushbutton, integrated LED*
- (optional: RJ45 jacks (2x))
- (optional: epaper display+conncetion wire)

Assembly Steps Overview

1. Frame assembly
- 1.1 nuts into t-slot profile (
- 1.2 place profile in rectangle, place corner elements between profiles, screw together
- 1.3 repeat

- -> result: 2 connected rectangle frame
- 1.4 connect the 2 rectangle frames with profile
- -> result: boxframe
2. screw bottom plate on bottom side of boxframe
- -> result: boxframe with bottom plate
3. cut and crimping wires
- 3.1 ...
4. battery pack assembly -> !!!!!safety note!!!!!
- 4.1 put battery cells in battery case (bottom part)
- 4.2 connect battery cells together
- 4.3 connect balancing wires with cells
- 4.4 connect power wires with battery cells
- 4.5 screw battery pack with bottom plate
5. mouting of electric components

## Assembly

Assembly frame box

!!! For the framebox assembly we urgently recommend to use the detailed step-by-step-guide at

https://github.com/case06/libresolarbox-v2_mobile/raw/main/doc/boxassemblyguide1d_osegci.pdf

and see the framebox BOM at

https://github.com/case06/libresolarbox-v2_mobile/raw/main/doc/bom_boxframe.pdf

Note: square nuts are not symmetric. When inserting them into T-Slot, keep the upper part outside. See picture [...] to determine the upper side of the nuts.

Create large squre frames first.

* Put larger profiles on the table and put plastic corners in the corners. Check orientation of the profiles. The holes on the side of the upper and the

lower profile must be up.

* Insert all necessary square nuts in the T-slots.

Hint: Use a bolt to push a square nut into a slot.

* Control the placement of corners, screws and squre nuts.

Start with the bottom part.

* Connect a corner to the bottom.

* Connect a side part to the bottom.

* Connect another corner to the bottom.

* Connect another side to the bottom.

* Connect remaining corners and the upper part.

* Connect small T-profiles to a big square frame. The holes on the side of the large frame must be later outside of the box.

* Insert nuts into short profiles.Two nuts into the short profiles on the top of the future box.Four nuts into every short profile on the bottom of the future box.
* Add the bottom blending.

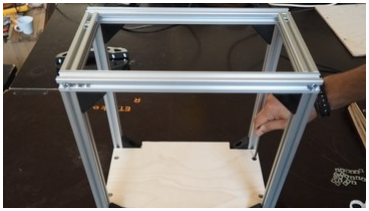
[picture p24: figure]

Add batteries

* Mark the batteries with numbers *1*, *2*, *3*, and *4*.

* Put batteries into the battery case.

* Isolate main **+** and main **-** of the batteries.

Now carrefully connect batteries one by one, from *4* to *1*.

* Put connector between *4* and *3*.

* Put a washer on the connector on the side *4*.

* Put thin cable with tag *4* on the washer

* Put another washer on the connector of the thin cable.

* Put a screw throw connector, washers and thin cable and tighten it.

* Put a washer on connector on side *3*.

* Put a screw throw the washer and the connector and tighten it.

* Connect in the simmilar way batteries *3* with *2* and *2* with *1*.

* Do **not** remove isolation from main **+** and main **-** yet.

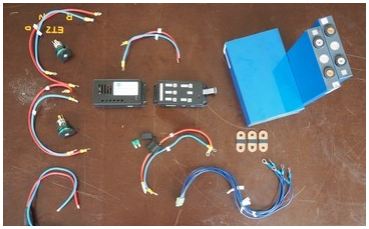
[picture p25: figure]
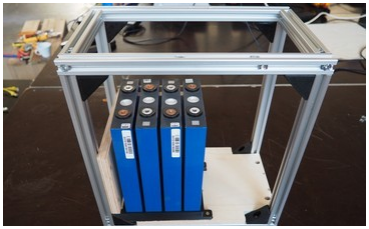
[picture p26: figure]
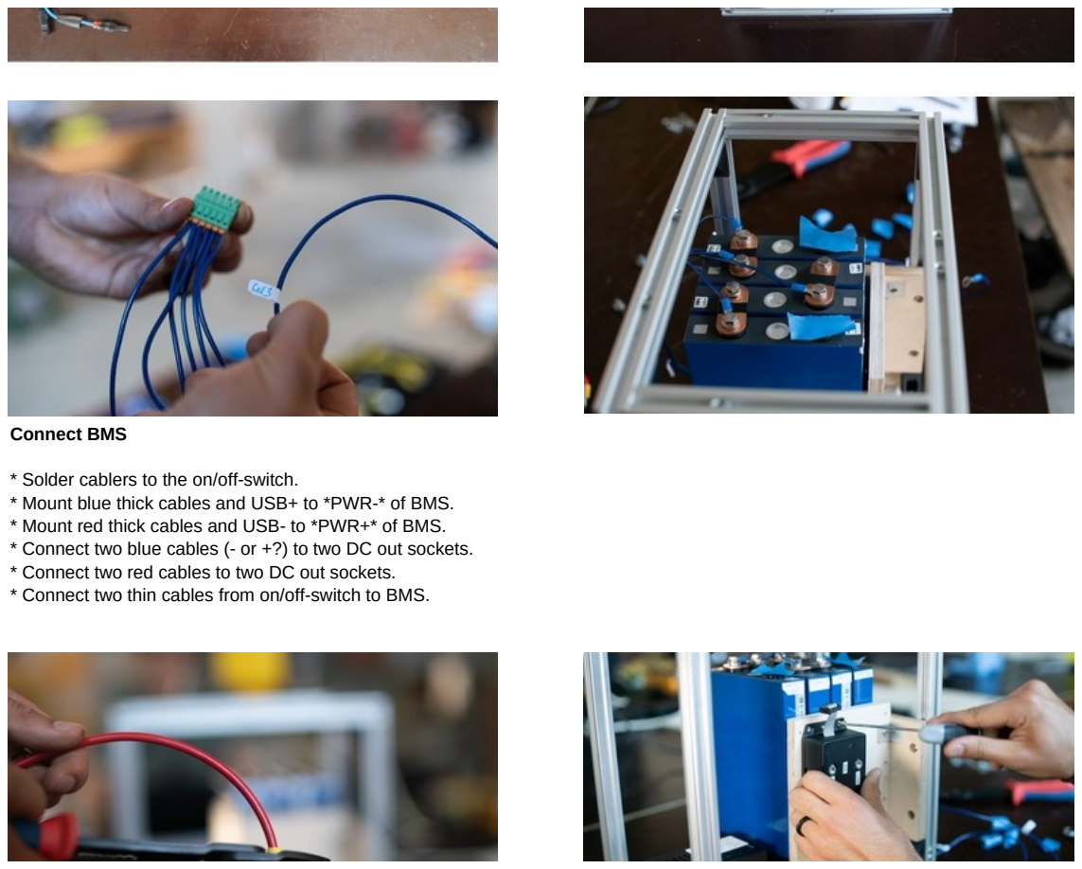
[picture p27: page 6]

Connect BMS

* Solder cablers to the on/off-switch.

* Mount blue thick cables and USB+ to *PWR-* of BMS.

* Mount red thick cables and USB- to *PWR+* of BMS.

* Connect two blue cables (- or +?) to two DC out sockets.

* Connect two red cables to two DC out sockets.

* Connect two thin cables from on/off-switch to BMS.

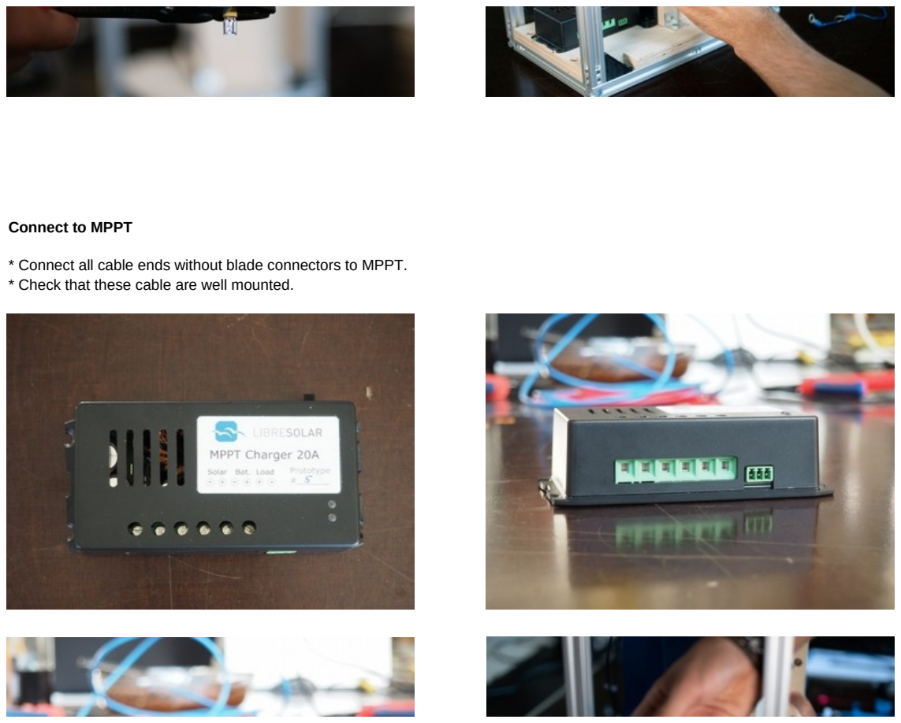
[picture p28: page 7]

Connect to MPPT

* Connect all cable ends without blade connectors to MPPT.

* Check that these cable are well mounted.

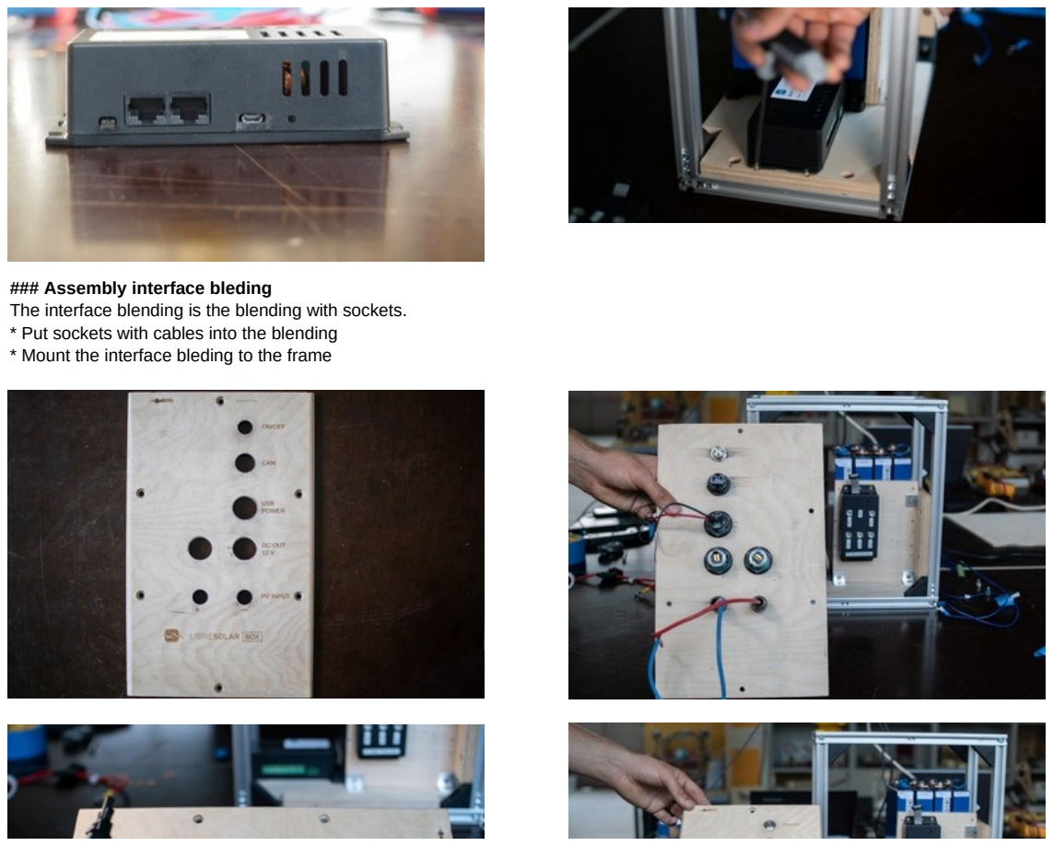
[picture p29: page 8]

### Assembly interface bleding

The interface blending is the blending with sockets.

* Put sockets with cables into the blending

* Mount the interface bleding to the frame

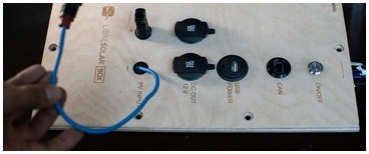
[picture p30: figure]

### Connect battery block

* Remove isolation from **main -**.

* Connect two cables to **main -**.

* Connect thick blue cable to *BAT-* on BMS.

* Connect two cables to **main -**

* Connect balancing to *BAT-* on BMS.

* Add fuse.

* Check the voltage: It must be around 12.8 V.

* Switch off the on/off switch.

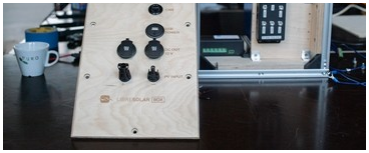
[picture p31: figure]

* Check the voltages. It must be falling until 0. The voltage does not drop imidiatelly to 0, because there is remaining electric charge in the capacitors.

* Swich on.

* Check Voltage between *POW+* and *POW-*. It must be about 12.8V.

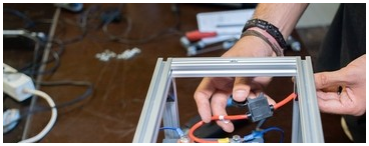
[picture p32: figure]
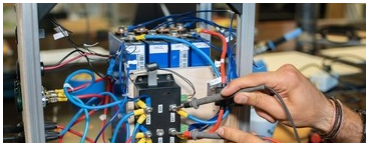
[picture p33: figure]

### Connect Raspberry

* Connect an internet cable to Raspberry

* Connect the internet cable to BMS.

* Connect an internet cable to CAN socket on the blending.

* Connect the other end of the cable to BMS.

* Mount the Raspbery with two-side tape to the box.

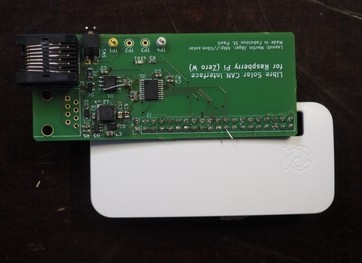
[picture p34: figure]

### Add back blending

(Better do it before interface blending because the inteface blending is not flat.)

* Put SolarBox on the interface.

* Position square nuts. They must have the same position as the holes of the blending.

* Put blending on the frame.

* Insert bolts through the blending into the square nuts. Tighten the bolts.

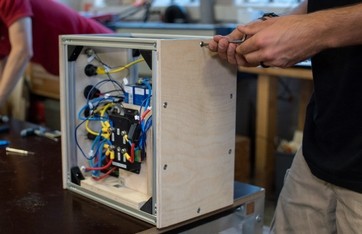
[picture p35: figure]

### Mount side blending

* Put the SolarBox on the side.

* Position the squre nuts.

* Put the blending on the frame.

* Insert bolts through the blending into the square nuts. Tighten the bolts.

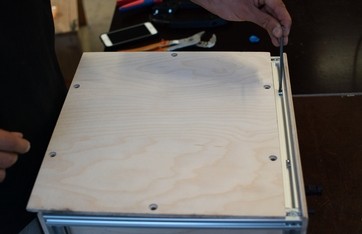
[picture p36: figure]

### Mount to blending with handles.

* Put the SolarBox on the bottom.

* Position squre nuts for the top blending.

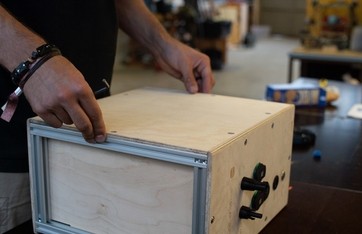
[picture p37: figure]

* Put top blending.

* Put handles on the top blending.

* Insert **longer** bolts through the handles, the blending and squre nuts. Use normal bolts for other parts of the blending.
* Tighten the blending.

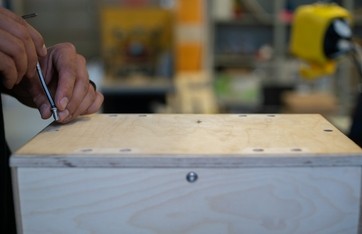
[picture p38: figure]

### Mount last side blending

* Check once more if all the connection are good.

* Insert the fuse.

* Put the SolarBox on the side.

* Position the square nuts.
* Add the blending.

* Tighten the bolts.

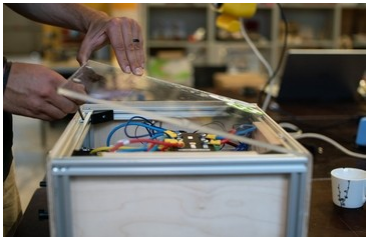
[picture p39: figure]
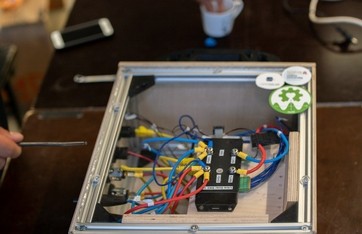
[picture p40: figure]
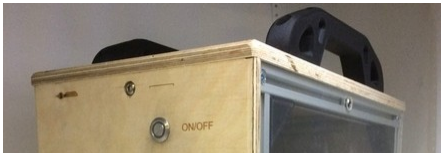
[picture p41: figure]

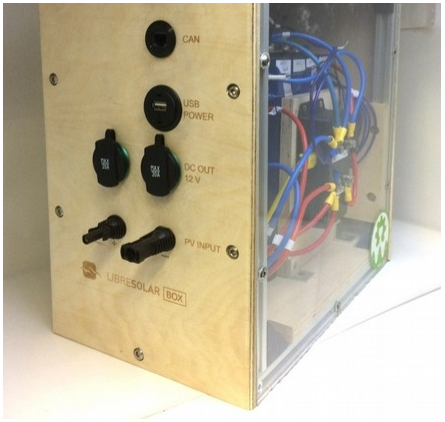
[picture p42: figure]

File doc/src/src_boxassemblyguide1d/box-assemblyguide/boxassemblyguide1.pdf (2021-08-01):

# Universal Prototyping Kit

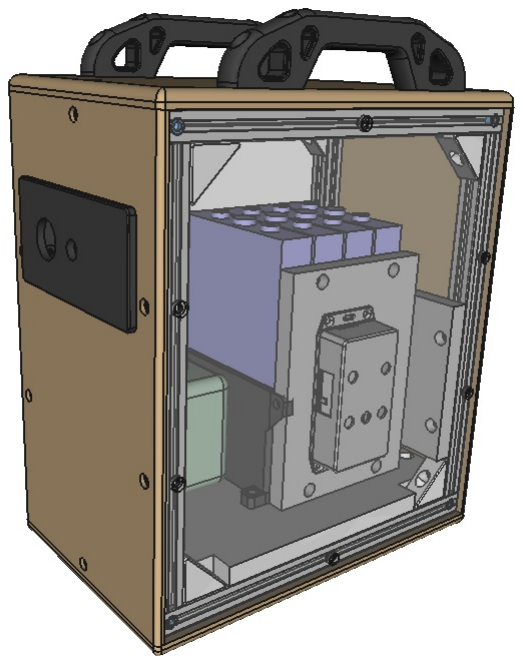
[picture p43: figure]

## UniProKit Box-Set UPKlib V. 2.02 Boxframe V.2 mobile Assembly Guide by OpenEcoLab Rahden, 08/2018

But in practice you may find it a bit tricky, to preplace the needed nutplates into the right slot for later use, eg. if you have finished the naked frame and then want to add the coverplates or other interieur
which assumes that there is already

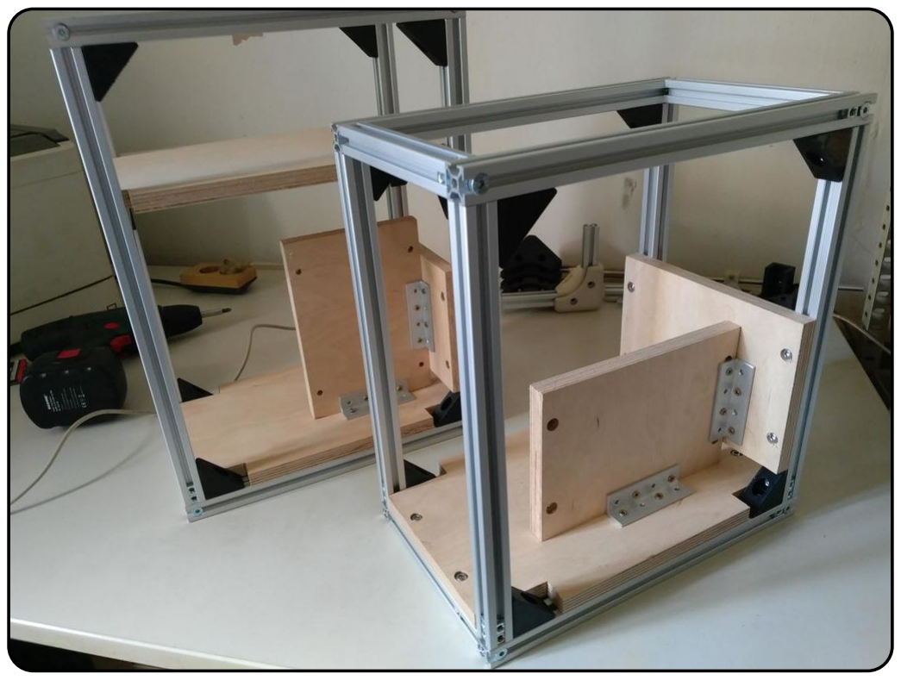
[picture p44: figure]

an appropriate nutplate in place, or better said in one certain slot of the extrusionprofile.

Depending on the stage of the assembly process it can either be still possible to move a nutplate into a slot, or not, Especially as more as you build up the frame some slots may be blocked eg. by the cornerscrews or by other beams. In this case there should already be one or more nutplates enclosed into the slot.

So its the best, to follow a certain choreography, movin some nuts into slots, then assemble a beam which encloses them.

Then again move some nuts into just these slots, which will be enclosed in the next assemblystep.

The guide aims to keep you an overview, which nuts to insert into which slot at a given step and then shows the next assembly step, to help you avoid forgetting some nutplates and having to disassemble later certain corners for moving the forgoten nutplates into it.

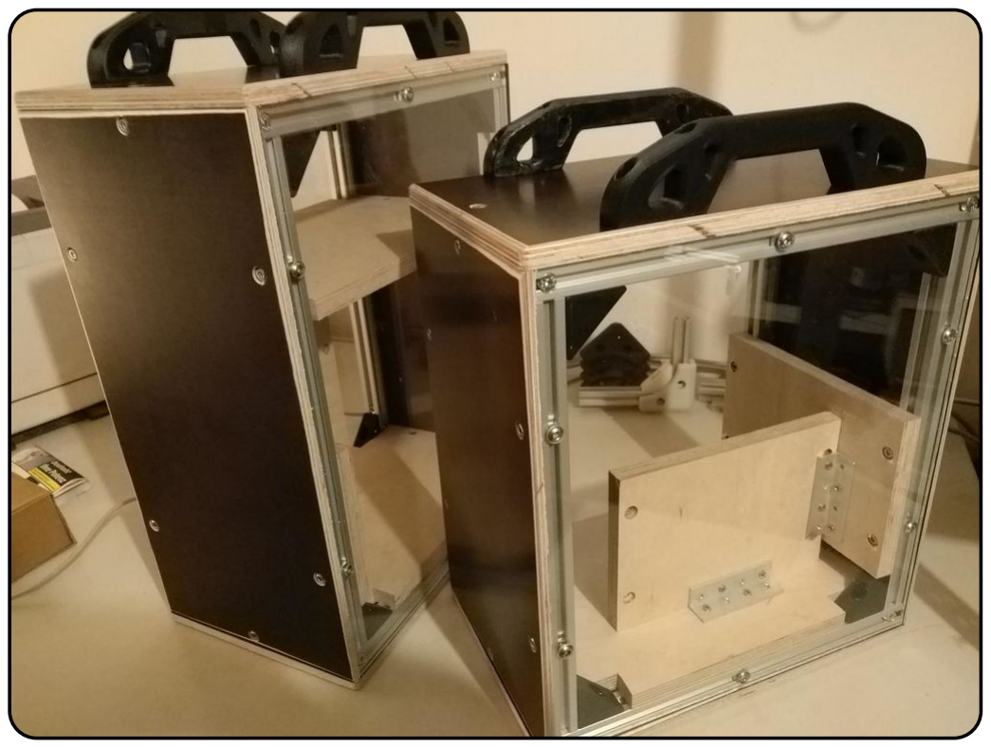
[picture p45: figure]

It's a bit like solving a rubikscube, as long as every step is applied at the right time and the right order, solving the puzzle is quick and easy.

Furthermore we start with building the upper frame, the lower frame and the upright pillars as sub-
assemblygroups, | before
connecting all totgether to a threedimensional framestructure.

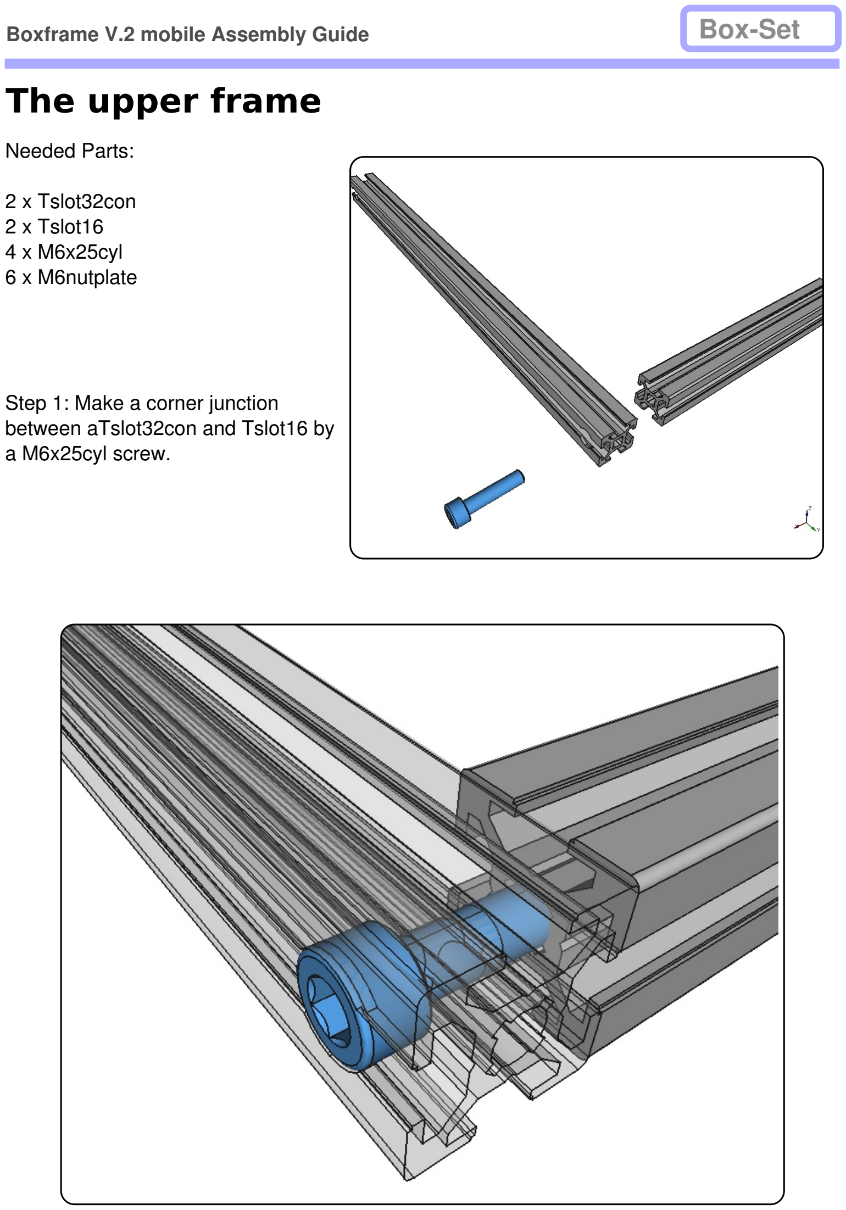
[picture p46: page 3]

Boxframe V.2 mobile Assembly Guide | Box-Set

Needed Parts:

2 x Tslot32con
2 x Tslot16
4 x M6x25cyl
6 x M6nutplate
Step 1: Make a corner junction between aTslot32con and Tslot16 by a M6x25cyl screw.

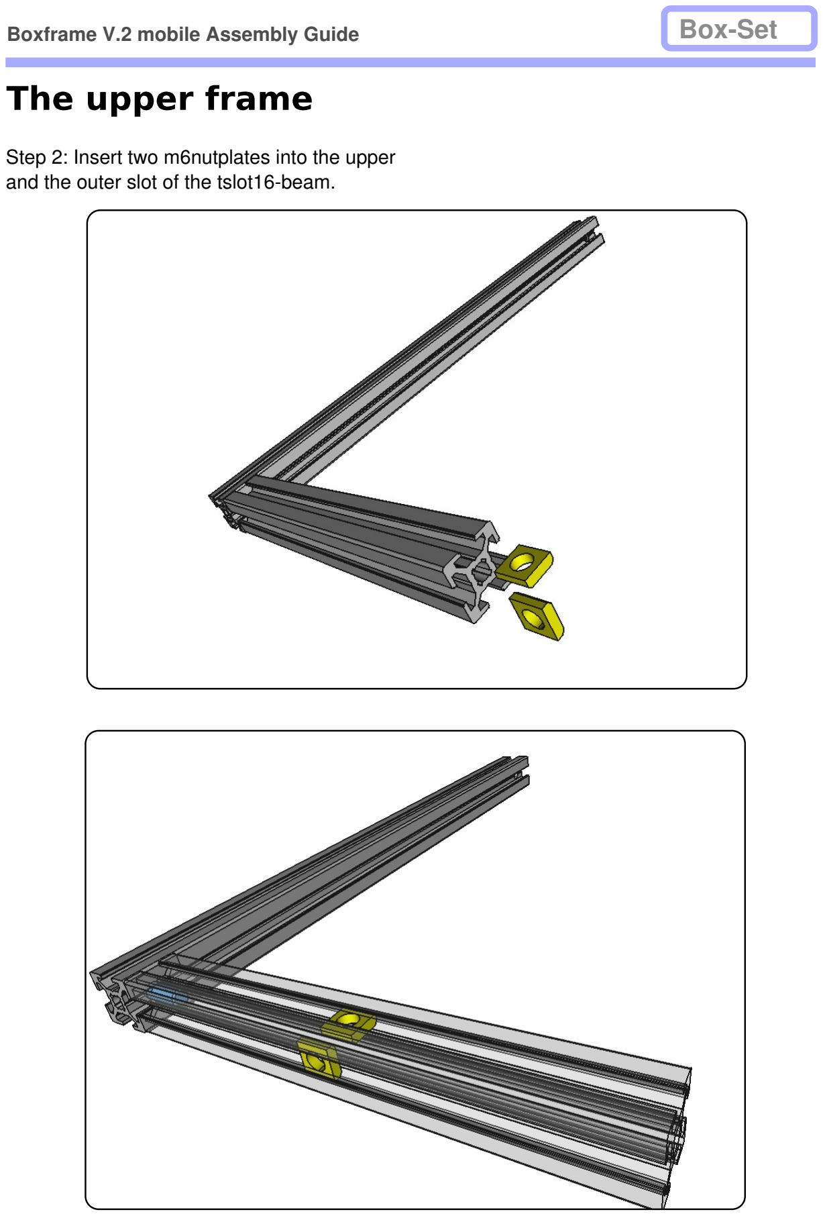
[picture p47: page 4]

Boxframe V.2 mobile Assembly Guide | Box-Set
Step 2: Insert two m6nutplates into the upper and the outer slot of the tslot16-beam.

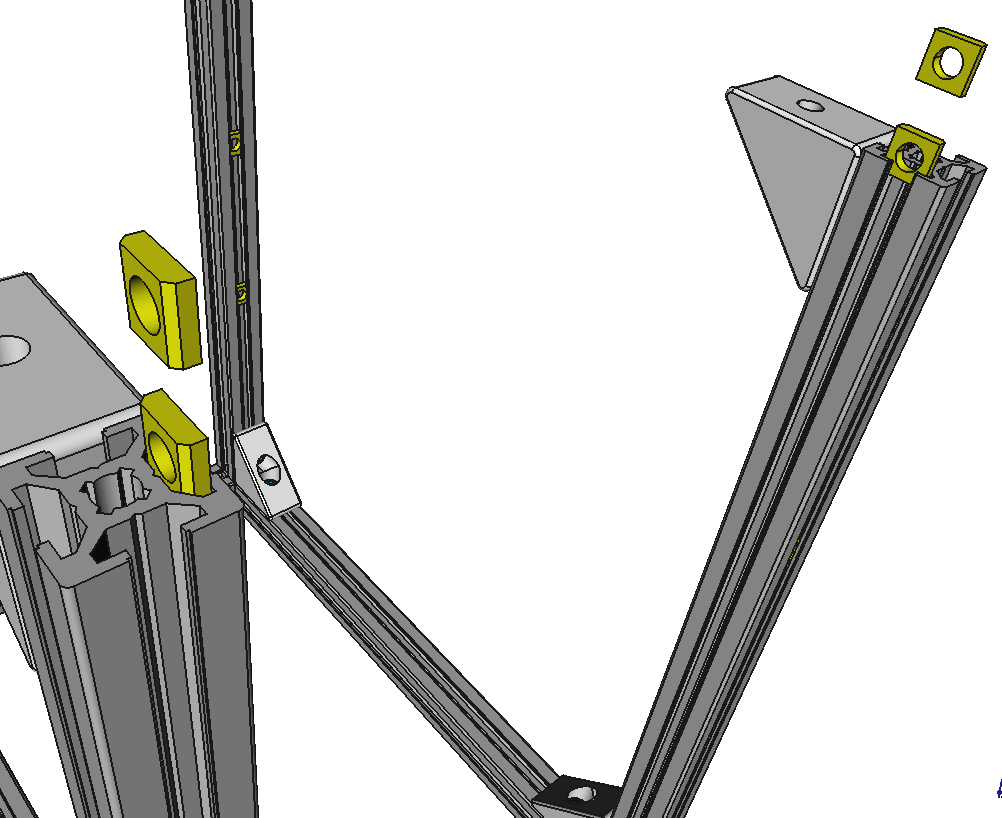
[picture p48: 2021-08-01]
doc/src/src_boxassemblyguide1d/rawframe/junction12.png

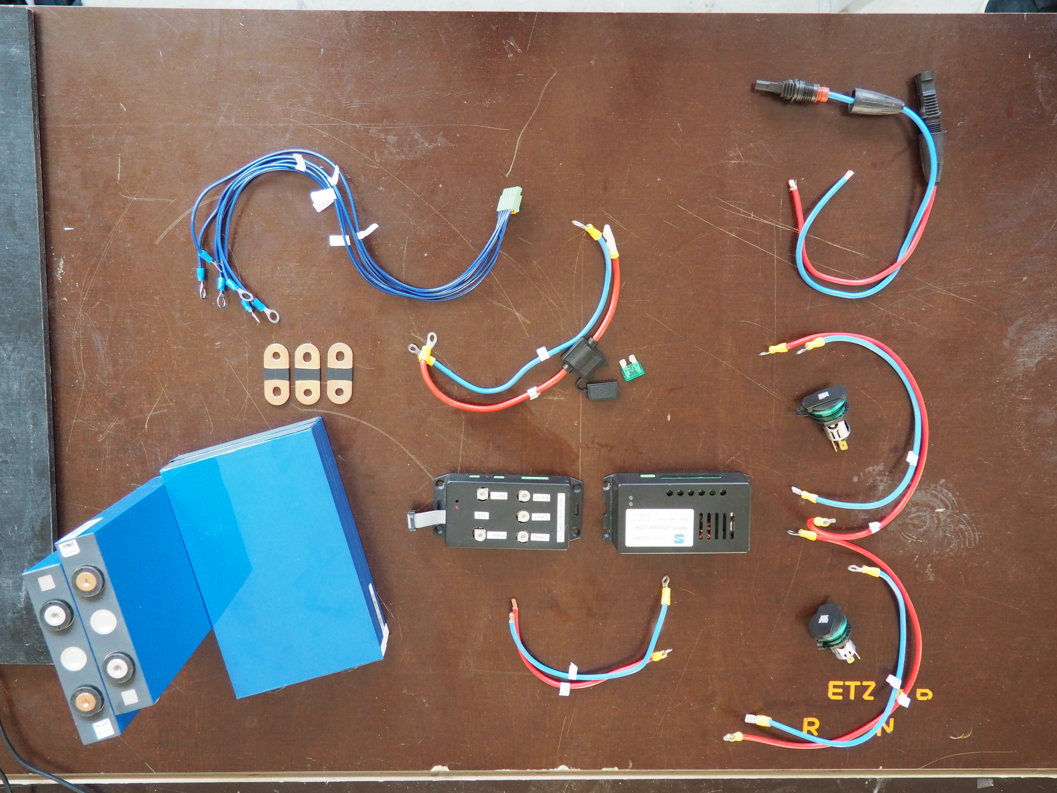
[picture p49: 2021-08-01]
doc/src/images/assembly_day_08.07.18/P7080125.JPG

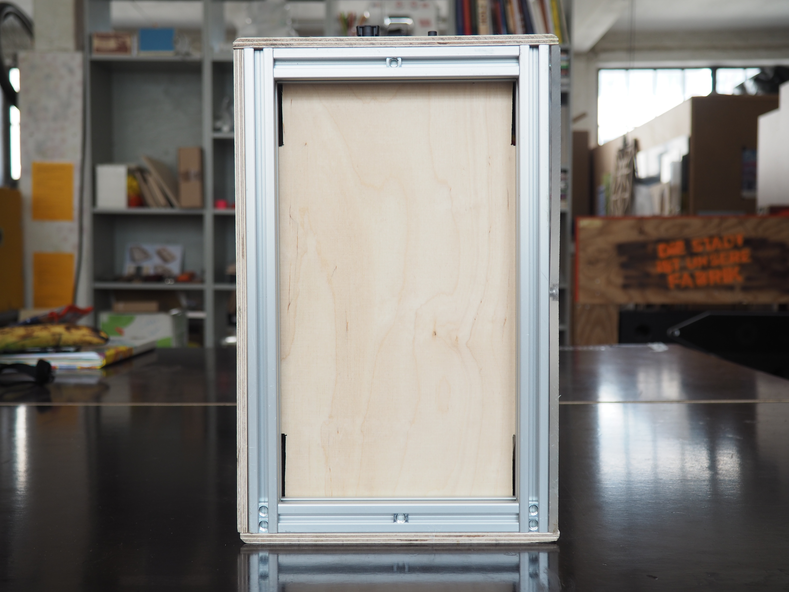
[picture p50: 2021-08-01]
doc/src/images/assembly_day_08.07.18/P7080077.JPG

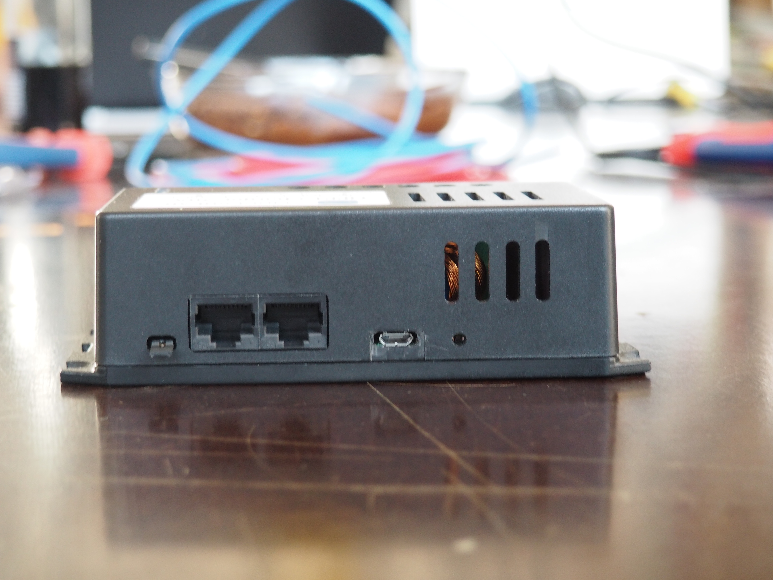
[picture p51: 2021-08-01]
doc/src/images/assembly_day_08.07.18/P7080116.JPG

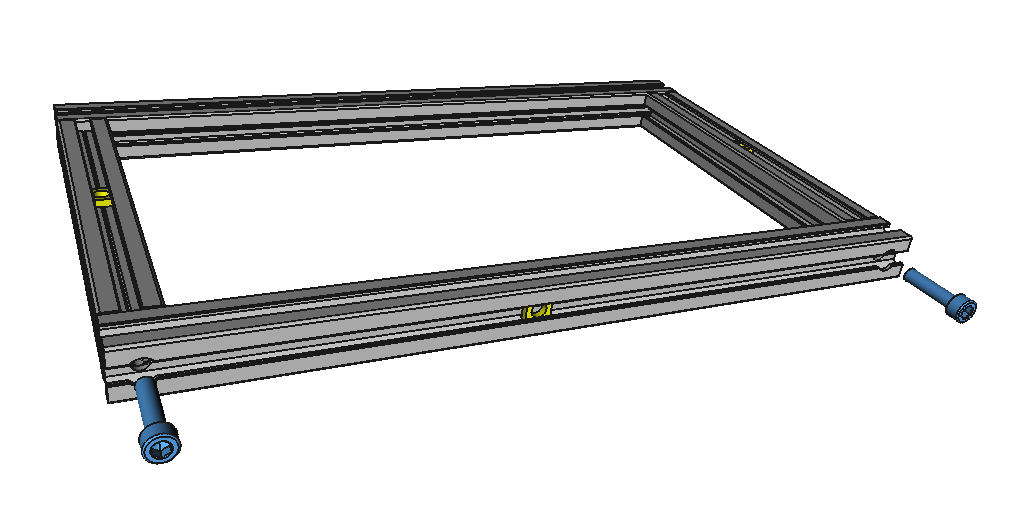
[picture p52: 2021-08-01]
doc/src/src_boxassemblyguide1d/upper_frame/frame10.png

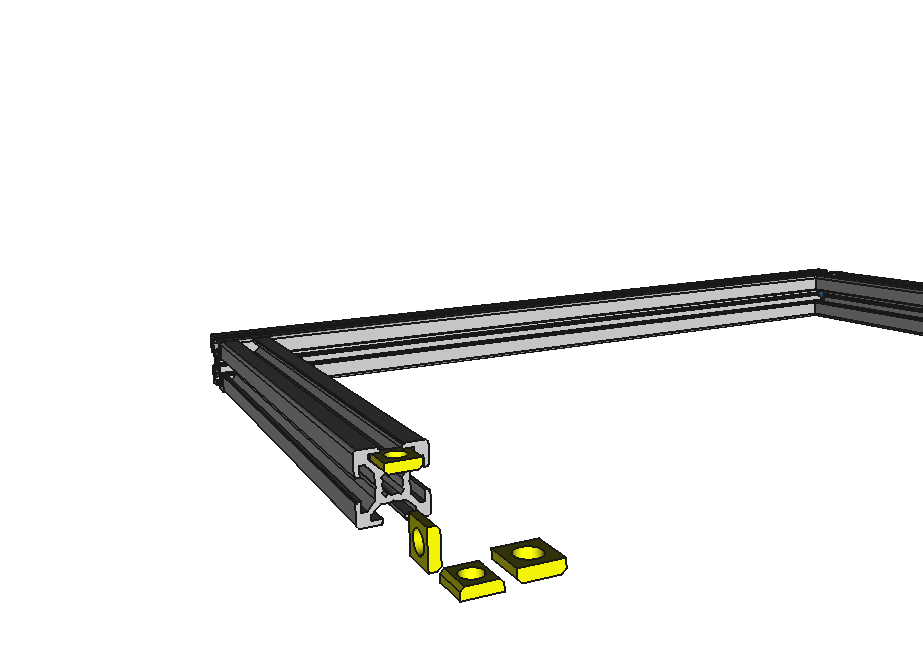
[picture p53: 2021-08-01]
doc/src/src_boxassemblyguide1d/lower_frame/lframe1.png

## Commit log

2021-08-01 initial release
    [UPKframeNG2j.FCStd, assembly_electronics_1c.ods, batterymount1c.fcstd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]
2021-08-01 changed readme
    [assembly_electronics_1c.ods]
2021-08-01 added bom-electronics
    [bom_electronics.ods]
2021-10-07 minor partname corrections in BOM
    [bom_boxframe.ods, bom_electronics.ods]
2021-11-27 adopted to DinSpec3105 reviewed gitlab repo
    [SolarBox_allparts.FCStd, assembly_electronics_1c.ods, assembly_electronics_1d.ods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]
2021-11-27 added ISO numbers to BOM
    [assembly_electronics_1d.ods, bom_boxframe.ods]
